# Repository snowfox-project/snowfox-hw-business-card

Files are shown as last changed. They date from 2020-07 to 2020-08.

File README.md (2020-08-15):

# Snowfox HW Business Card

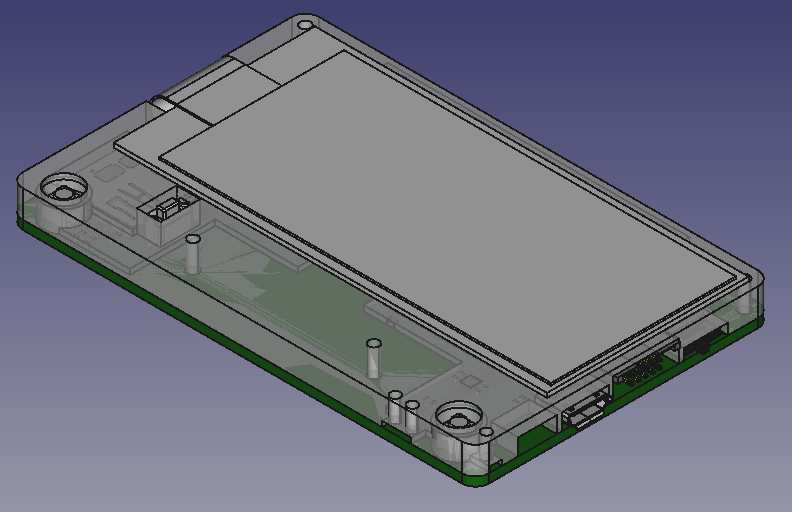
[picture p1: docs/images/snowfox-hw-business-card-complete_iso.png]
snowfox-hw-business-card-complete iso rendering


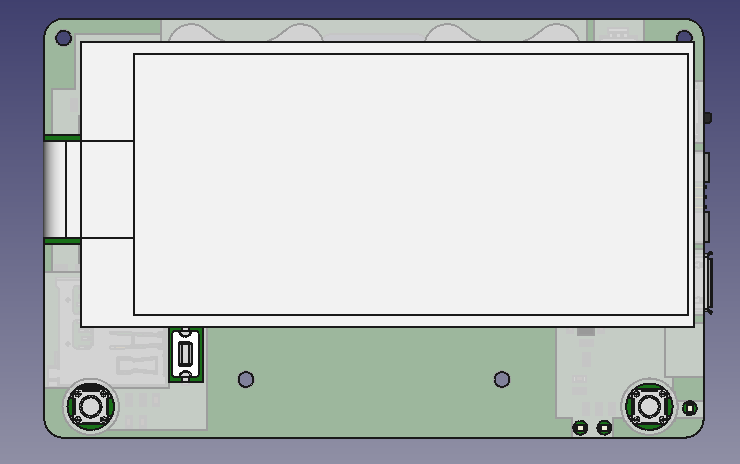
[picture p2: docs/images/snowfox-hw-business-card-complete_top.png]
snowfox-hw-business-card-complete top rendering


## PCB

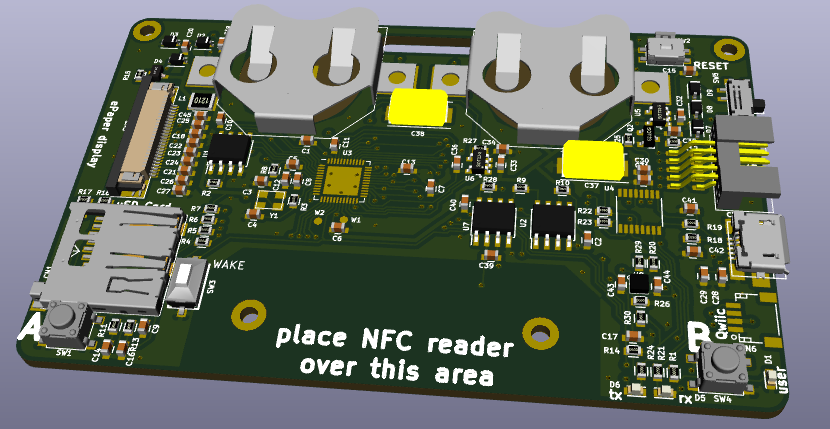
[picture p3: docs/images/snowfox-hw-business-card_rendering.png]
snowfox-hw-business-card rendering


### Top

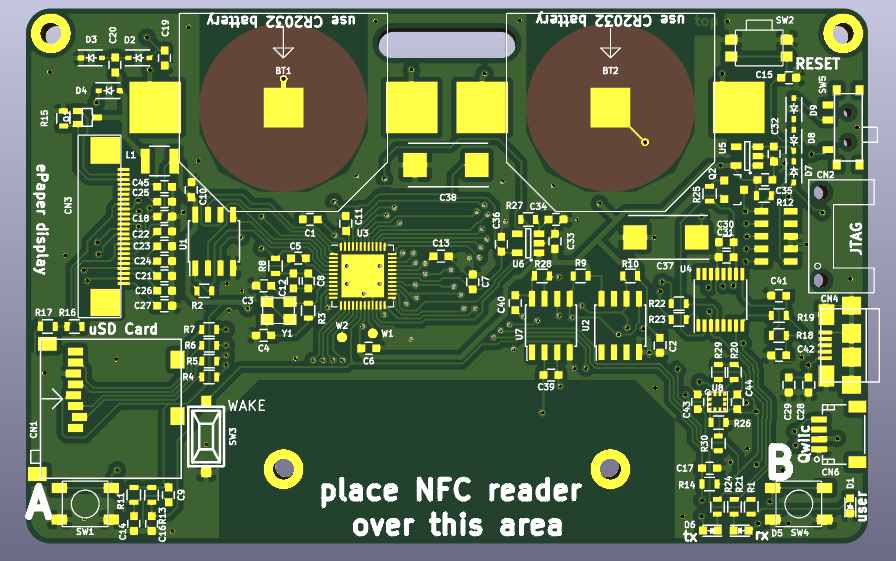
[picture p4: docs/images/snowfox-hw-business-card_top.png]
snowfox-hw-business-card PCB top


### Bottom

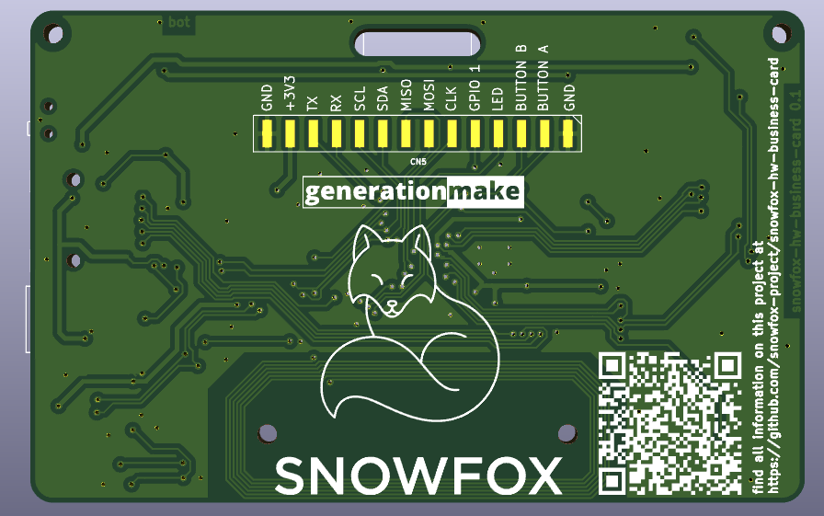
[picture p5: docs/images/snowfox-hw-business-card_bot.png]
snowfox-hw-business-card PCB bot


## Microcontroller

### pin usage

| pin | signal | direction | comment |
|-----|---|---|---|
| gpio_0 | LED | output | user led |
| gpio_1 | GPIO_1 | undefined | |
| gpio_2 | SPI_CS_SD | output | chip select SD card |
| gpio_3 | SPI_MOSI | output | |
| gpio_4 | SPI_MISO | input | |
| gpio_5 | SPI_CLK | output | |
| gpio_9 | SPI_CS_DIS | output | chip selecet display |
| gpio_10 | DIS_RESET# | output | display reset |
| gpio_11 | DIS_D_C# | output | display data/command |
| gpio_12 | I2C_SDA | bidir | I2C data |
| gpio_13 | I2C_SCL | output | I2C clock |
| gpio_16 | RX | input | serial rx to USB |
| gpio_17 | TX | output | serial tx to USB |
| gpio_18 | EXT_TX | output | serial tx to expansion connector |
| gpio_19 | DIS_BUSY | input | display busy |
| gpio_20 | NFC_BUSY | input | nfc busy |
| gpio_21 | BUTTON_A | input | button left |
| gpio_22 | BUTTON_B | input | button right |
| gpio_23 | EXT_RX | input | serial rx to expansion connector |

### i2c addresses

| address | device | comment |
|-----|---|---|
| 0x18 | BMA253 | accelerometer |
| 0x53 | M24LR | NFC eeprom - memory area |
| 0x57 | M24LR | NFC eeprom - security and data area |
| 0x60 | ATECC608A | crypto device |

The M24LR blocks two I2C adresses.

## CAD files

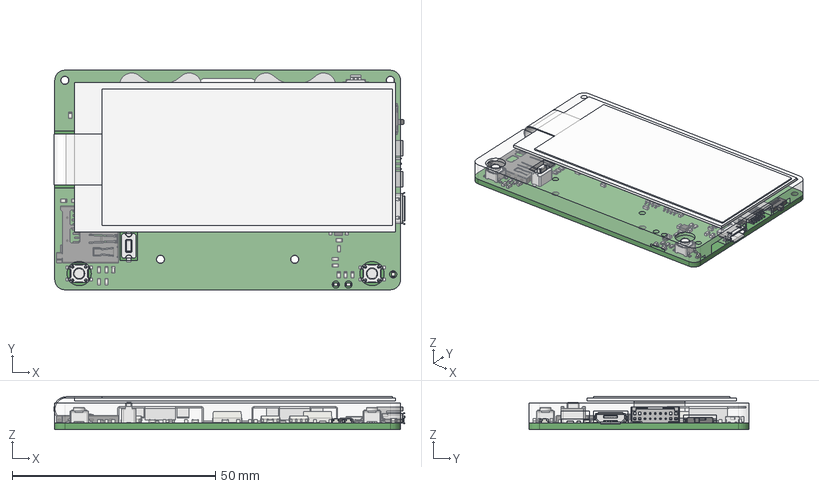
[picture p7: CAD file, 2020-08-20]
freecad_source/snowfox-hw-business-card-complete.FCStd
86.3 x 54.0 x 8.20 mm
display_frame

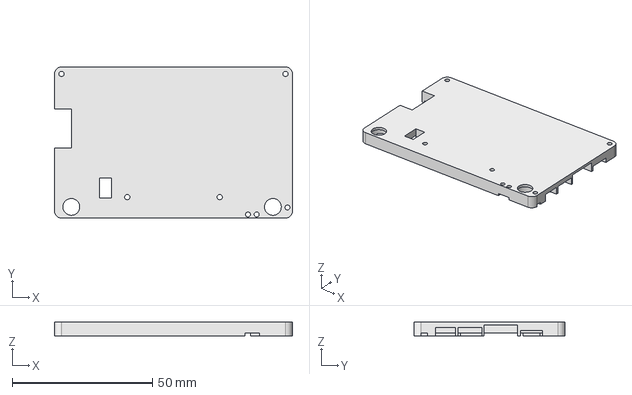
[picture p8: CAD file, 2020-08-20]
production_data/display_frame.step
85.0 x 54.0 x 5.00 mm

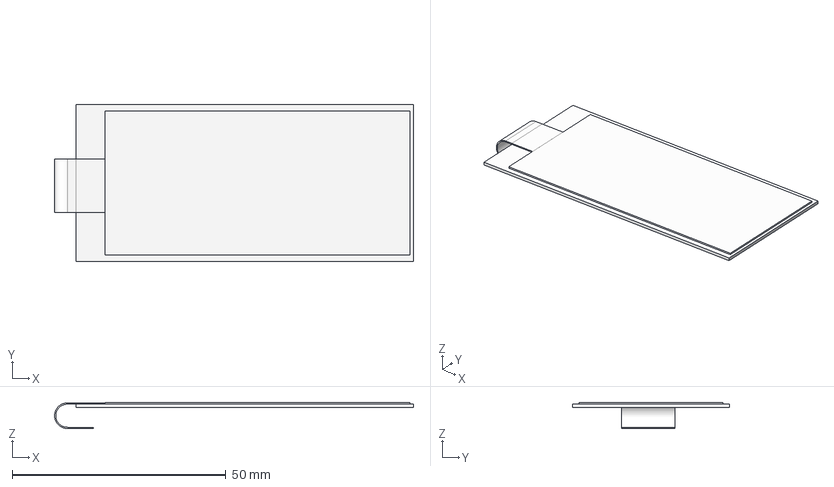
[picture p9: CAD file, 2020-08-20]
freecad_source/e-paper.step
84.0 x 36.7 x 6.10 mm

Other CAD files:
production_data/display_frame.stl

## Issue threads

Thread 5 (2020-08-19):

QR code on pcb silk screen not working

generationmake, 2020-08-19:
fix or remove.

aentinger, 2020-08-31:
I can confirm this. Would it be possible to make a less convoluted QR code? I believe we can't make it much bigger without occupying too much space on the PCB so if it can't be made simpler so that the PCB silkscreen printer can handle it I'd be leaning towards removing it.

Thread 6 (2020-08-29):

add vias in mechanical pads of USB connector

generationmake, 2020-08-29:
add vias to GND on bottom side in mechanical pads of the USB connector to give more mechanical stability and avoid loosening of USB connector (CN4).

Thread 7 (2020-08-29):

mark position of on/off switch in silk screen or similar

generationmake, 2020-08-29:
It is not clear in which position of the on/off switch the board is powered. We should mark the position in the silk screen.

aentinger, 2020-08-31:
I can confirm, it would definitely be helpful to mark both ON/OFF position on the bottom layer silk screen. Furthermore I suggest to also mark QWIIC, USB, JTAG as well as SD card (it doesn't cost any extra as we already print the silk screen at the bottom).

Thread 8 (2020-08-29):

JTAG connector seems to be twisted

generationmake, 2020-08-29:
The JTAG connector CN2 seems to be twisted.

Pin 1 is pin 10 and vice versa and so on.

aentinger, 2020-09-01:
I can confirm this observation. Fortunately this can be solved handily (for me right now) by turning around the plug on the Segger JLink CortexM Adapter.

When connecting with JLinkExe V6.82f I get the following output:
```bash
$ JLinkExe -device FE310 -if JTAG -speed 4000 -jtagconf -1,-1 -autoconnect 1
SEGGER J-Link Commander V6.82f (Compiled Aug 24 2020 12:19:09)
DLL version V6.82f, compiled Aug 24 2020 12:18:57

Connecting to J-Link via USB...O.K.
Firmware: J-Link V10 compiled Jul 17 2020 16:23:38
Hardware version: V10.10
S/N: 50116637
License(s): GDB
VTref=3.335V
Device "FE310" selected.

Connecting to target via JTAG
ConfigTargetSettings() start
ConfigTargetSettings() end
TotalIRLen = 5, IRPrint = 0x01
JTAG chain detection found 1 devices:
 #0 Id: 0x20000913, IRLen: 05, Unknown device
Debug architecture:
  RISC-V debug: 0.13
  AddrBits: 7
  DataBits: 32
  IdleClks: 5
Memory access:
  Via system bus: No
  Via ProgBuf: No (0 ProgBuf entries)
DataBuf: 0 entries
  autoexec[0] implemented: No
Failed to temporarily halt core during identification
Attaching to core failed. Trying again with connect under reset (ndmreset-bit)
Memory access:
Detected: RV32 core
CSR access via abs. commands: Yes
CPU could not be halted
ConfigTargetSettings() start
ConfigTargetSettings() end
ConfigTargetSettings() start
ConfigTargetSettings() end

****** Error: Timeout while waiting for core to halt after reset and halt request
Communication timed out: Requested 4 bytes, received 0 bytes !
Specific core setup failed.
Could not read hardware status!
Cannot connect to target.
J-Link>
```
When connecting to SiFive HiFive 1 Rev. B board I get:
```bash
alex@dragon:~$ JLinkExe -device FE310 -if JTAG -speed 4000 -jtagconf -1,-1 -autoconnect 1
SEGGER J-Link Commander V6.82f (Compiled Aug 24 2020 12:19:09)
DLL version V6.82f, compiled Aug 24 2020 12:18:57

Connecting to J-Link via USB...O.K.
Firmware: J-Link V10 compiled Jul 17 2020 16:23:38
Hardware version: V10.10
S/N: 50116637
License(s): GDB
VTref=3.322V
Device "FE310" selected.

Connecting to target via JTAG
ConfigTargetSettings() start
ConfigTargetSettings() end
TotalIRLen = 5, IRPrint = 0x01
JTAG chain detection found 1 devices:
 #0 Id: 0x20000913, IRLen: 05, Unknown device
Debug architecture:
  RISC-V debug: 0.13
  AddrBits: 7
  DataBits: 32
  IdleClks: 5
Memory access:
  Via system bus: No
  Via ProgBuf: Yes (16 ProgBuf entries)
DataBuf: 1 entries
  autoexec[0] implemented: Yes
Detected: RV32 core
CSR access via abs. commands: No
Temp. halted CPU for NumHWBP detection
HW instruction/data BPs: 8
Support set/clr BPs while running: No
HW data BPs trigger before execution of inst
RISC-V identified.
J-Link>
```
The source of this difference is currently unkown to me.

generationmake, 2020-09-02:
Hi @aentinger
Do you get the same result every time? Have you tried pushing the reset button in between?

Maybe the JLink adapter cannot handle the reset of the board?

Another difference could be the OTP ROM? Maybe it is programmed different?

generationmake, 2020-09-02:
maybe our pull up resistor on reset ist too strong? we have 10k. Hifive1 Rev B has 100k.

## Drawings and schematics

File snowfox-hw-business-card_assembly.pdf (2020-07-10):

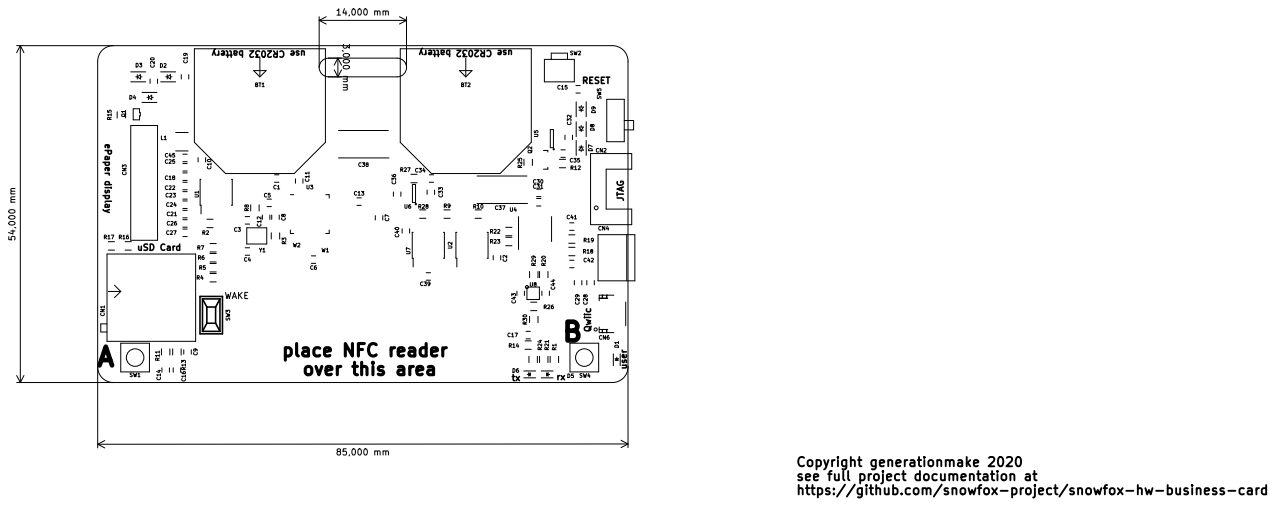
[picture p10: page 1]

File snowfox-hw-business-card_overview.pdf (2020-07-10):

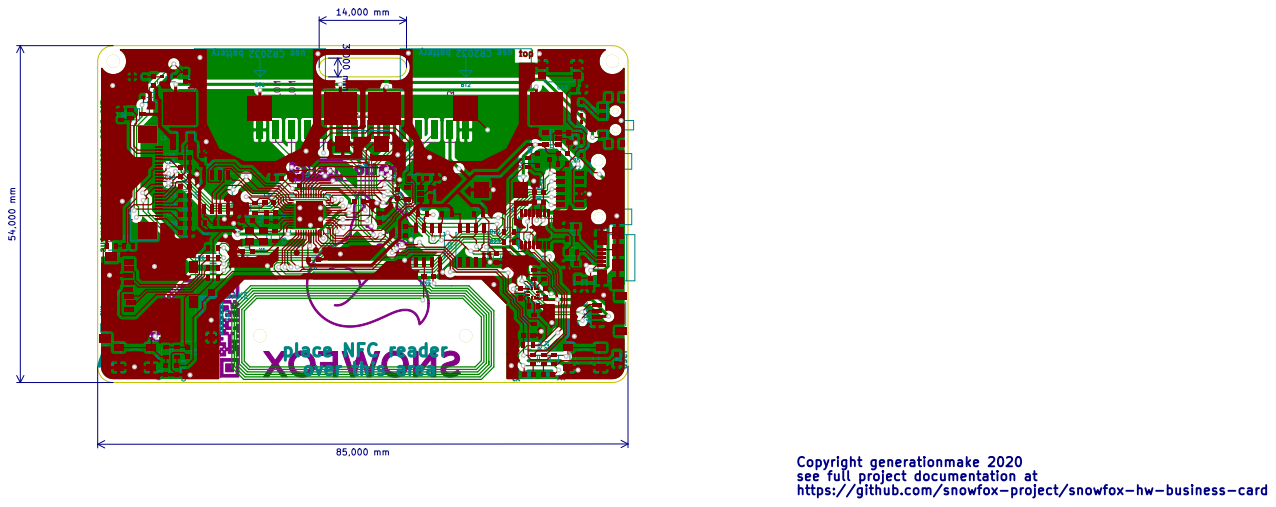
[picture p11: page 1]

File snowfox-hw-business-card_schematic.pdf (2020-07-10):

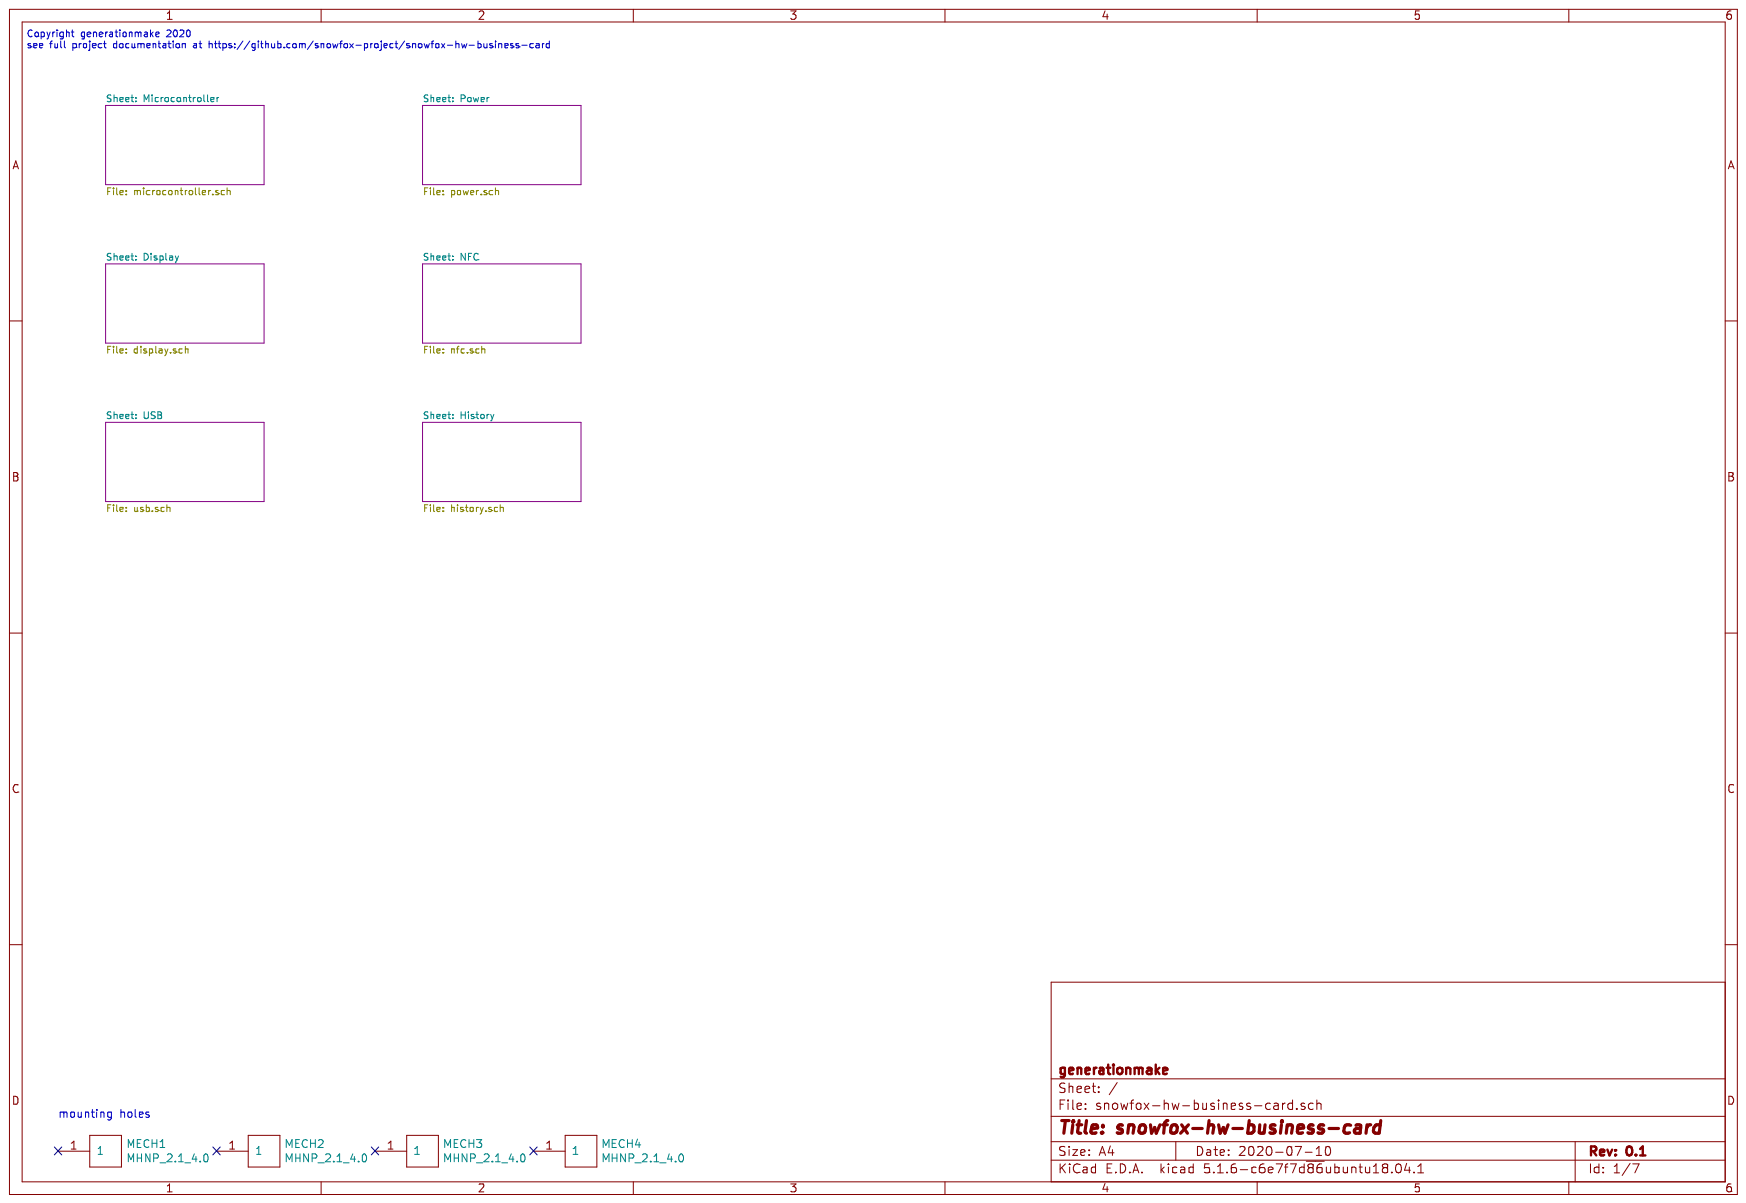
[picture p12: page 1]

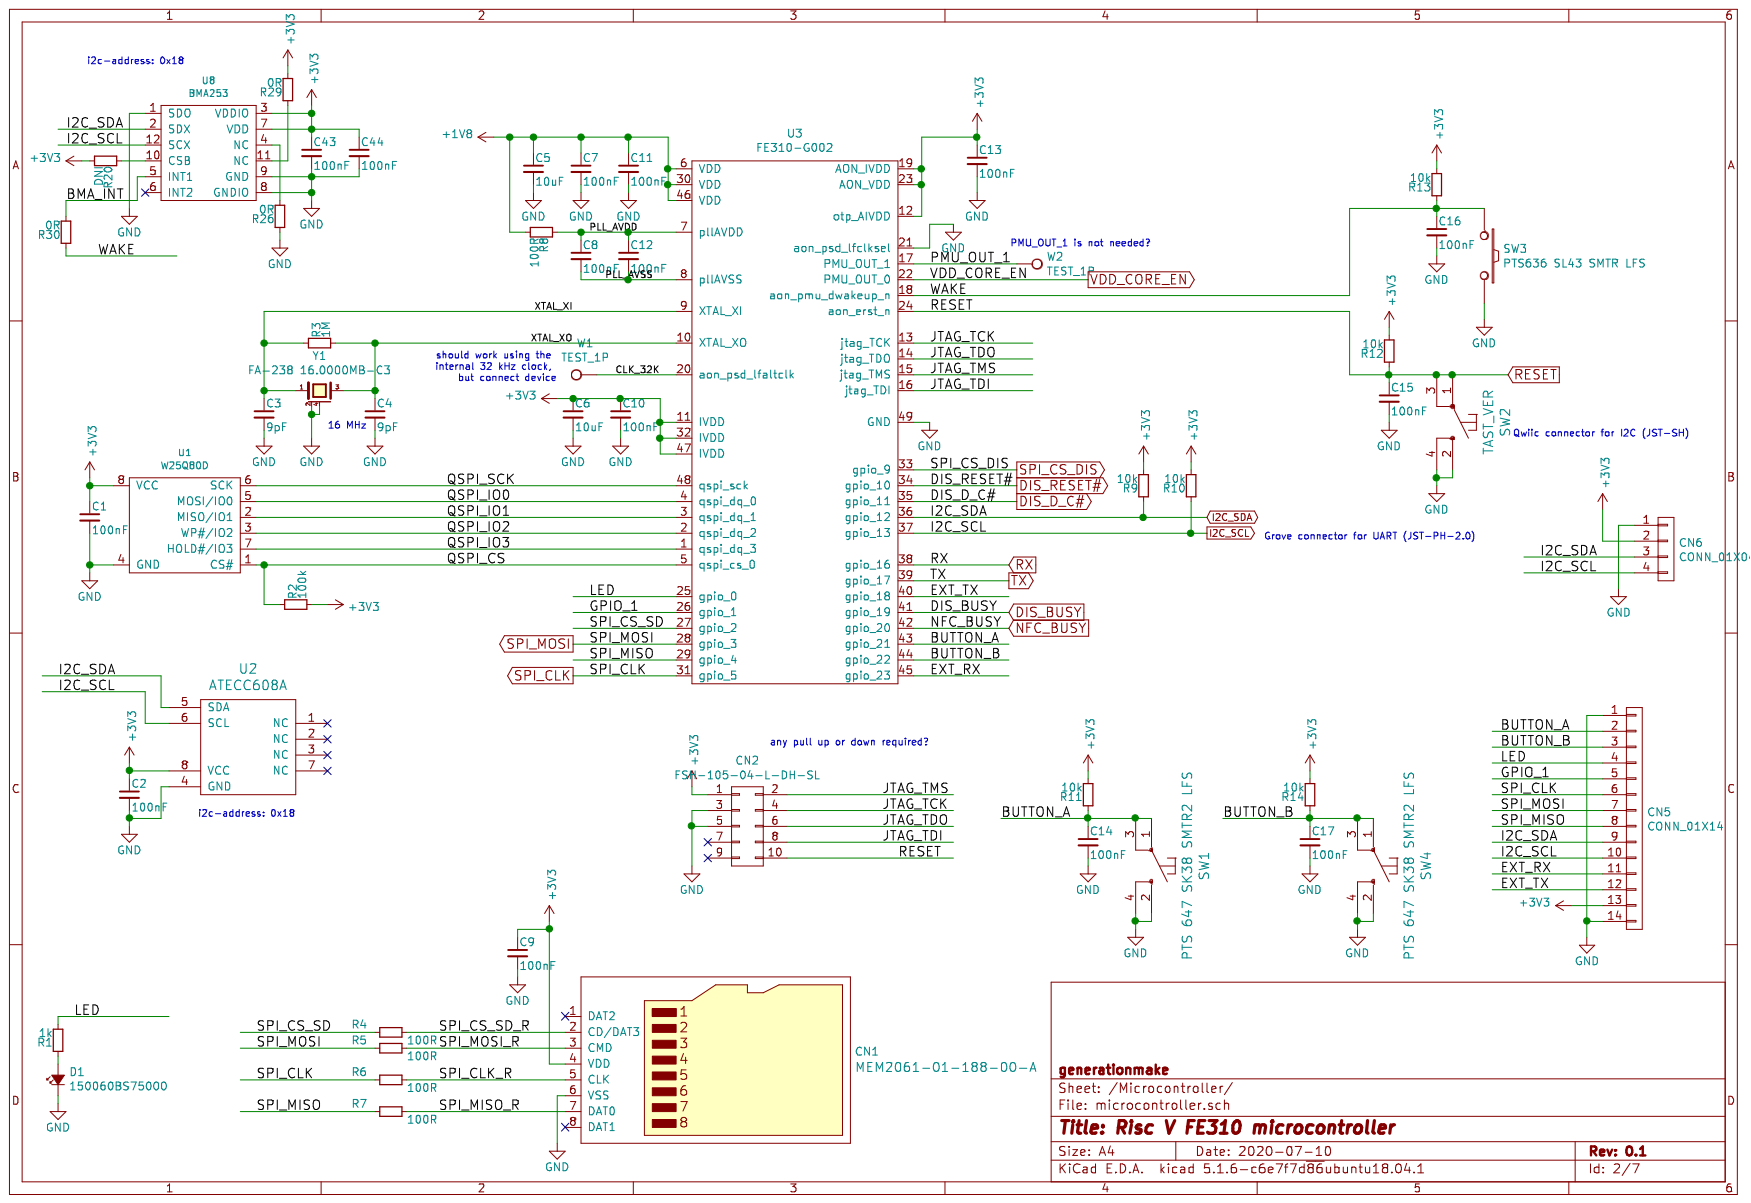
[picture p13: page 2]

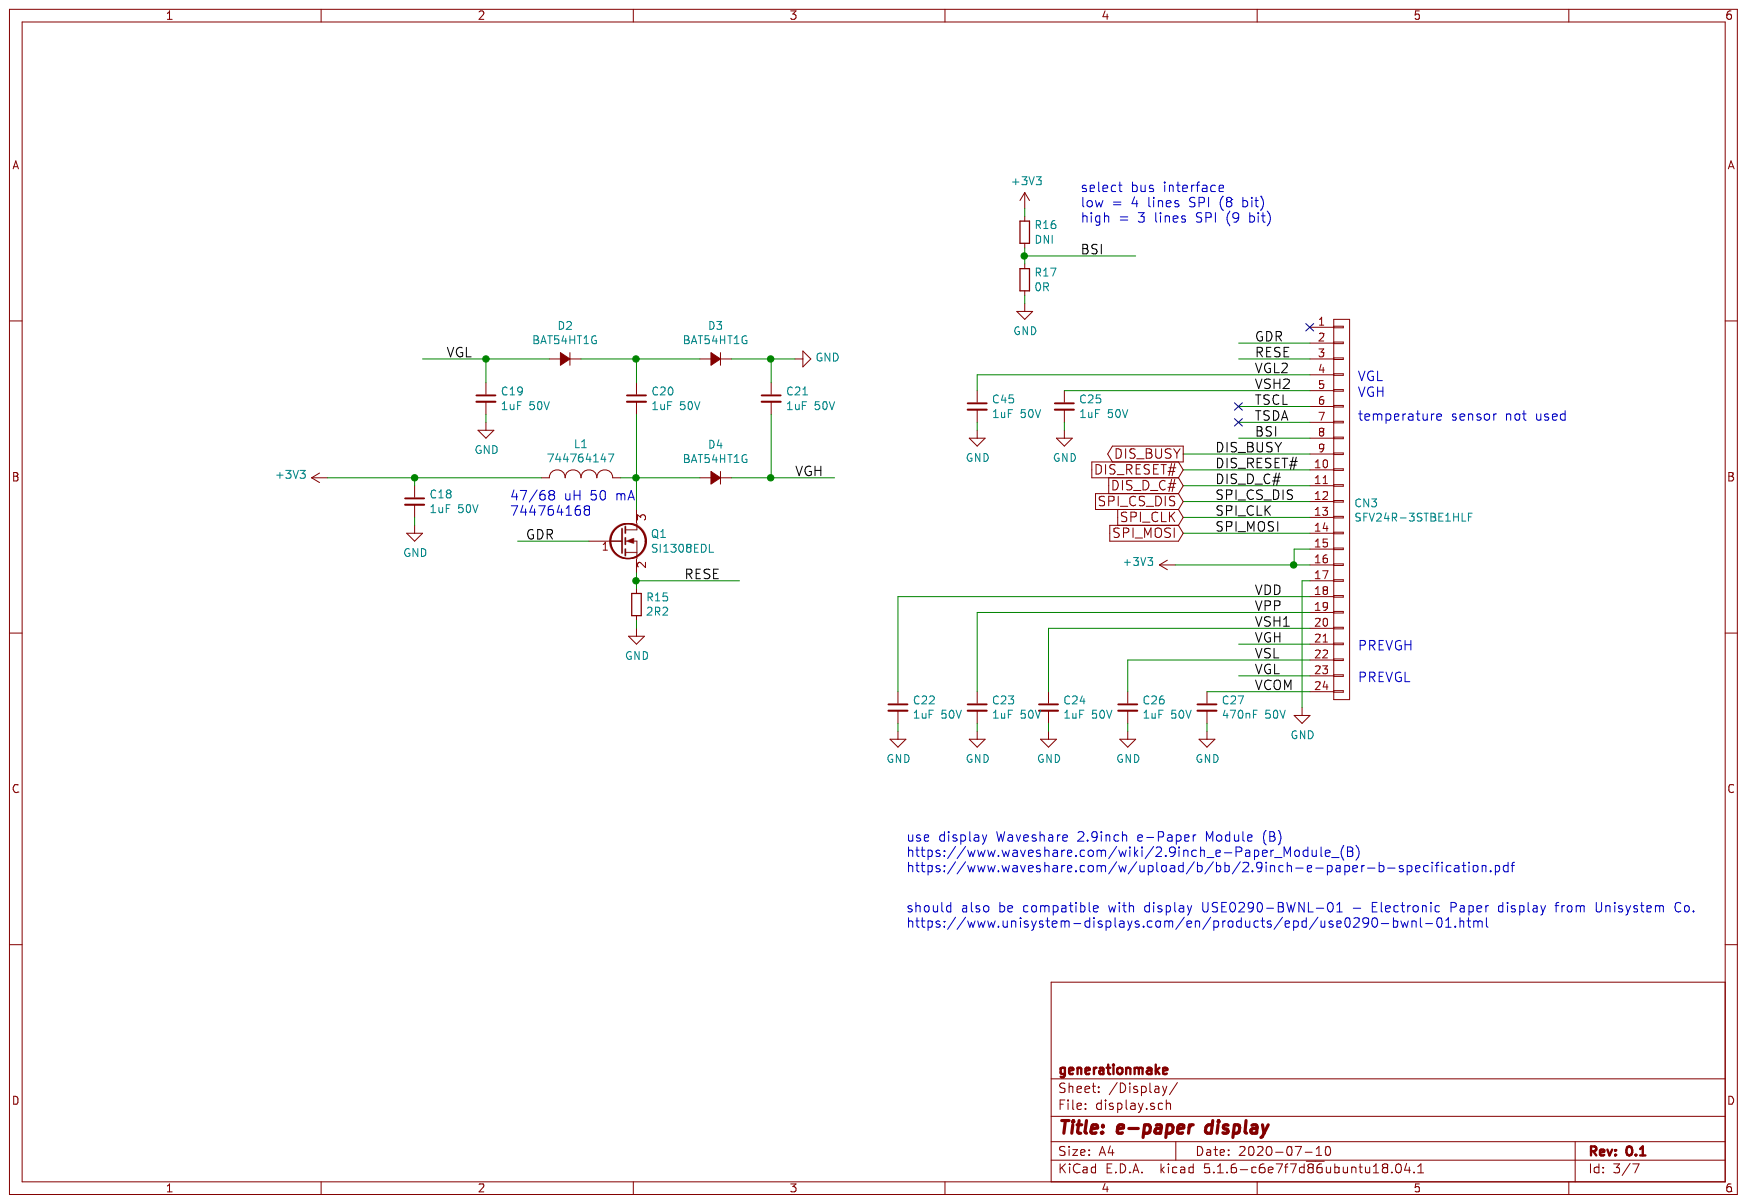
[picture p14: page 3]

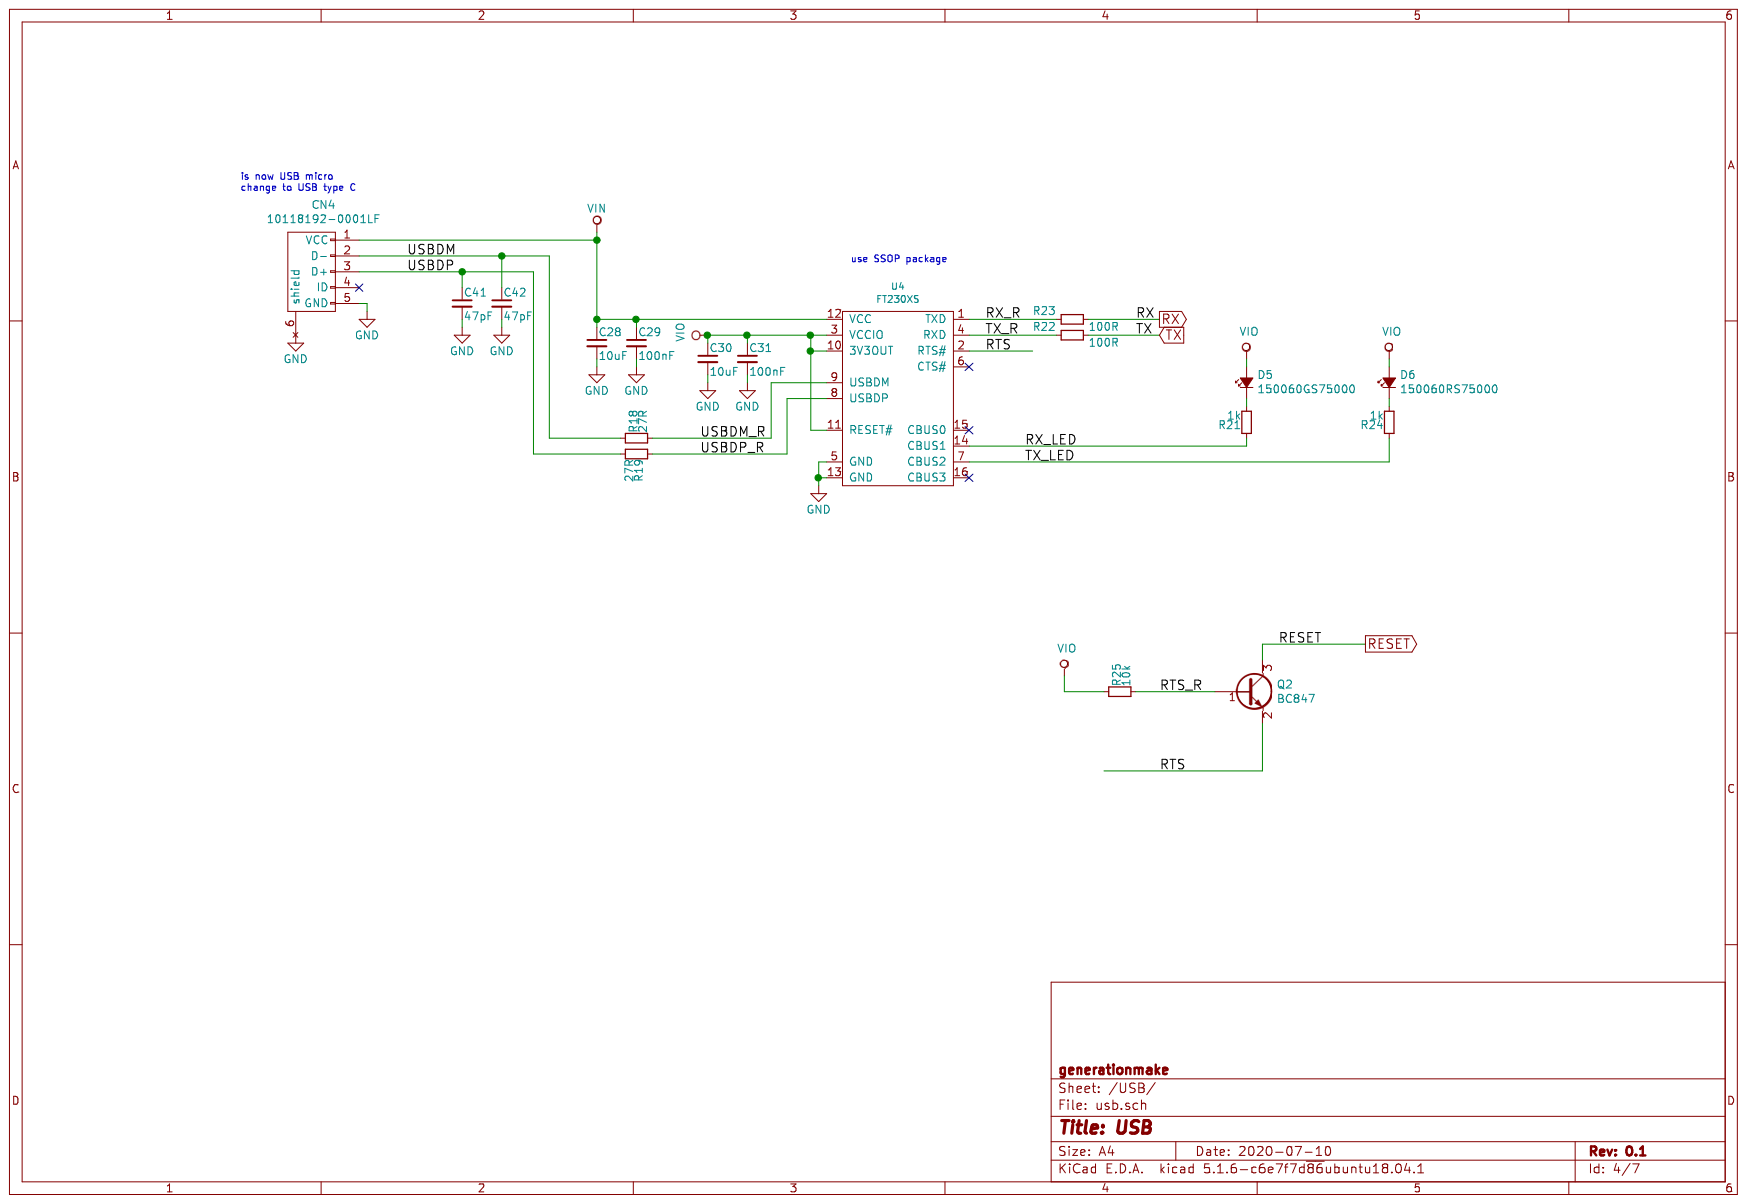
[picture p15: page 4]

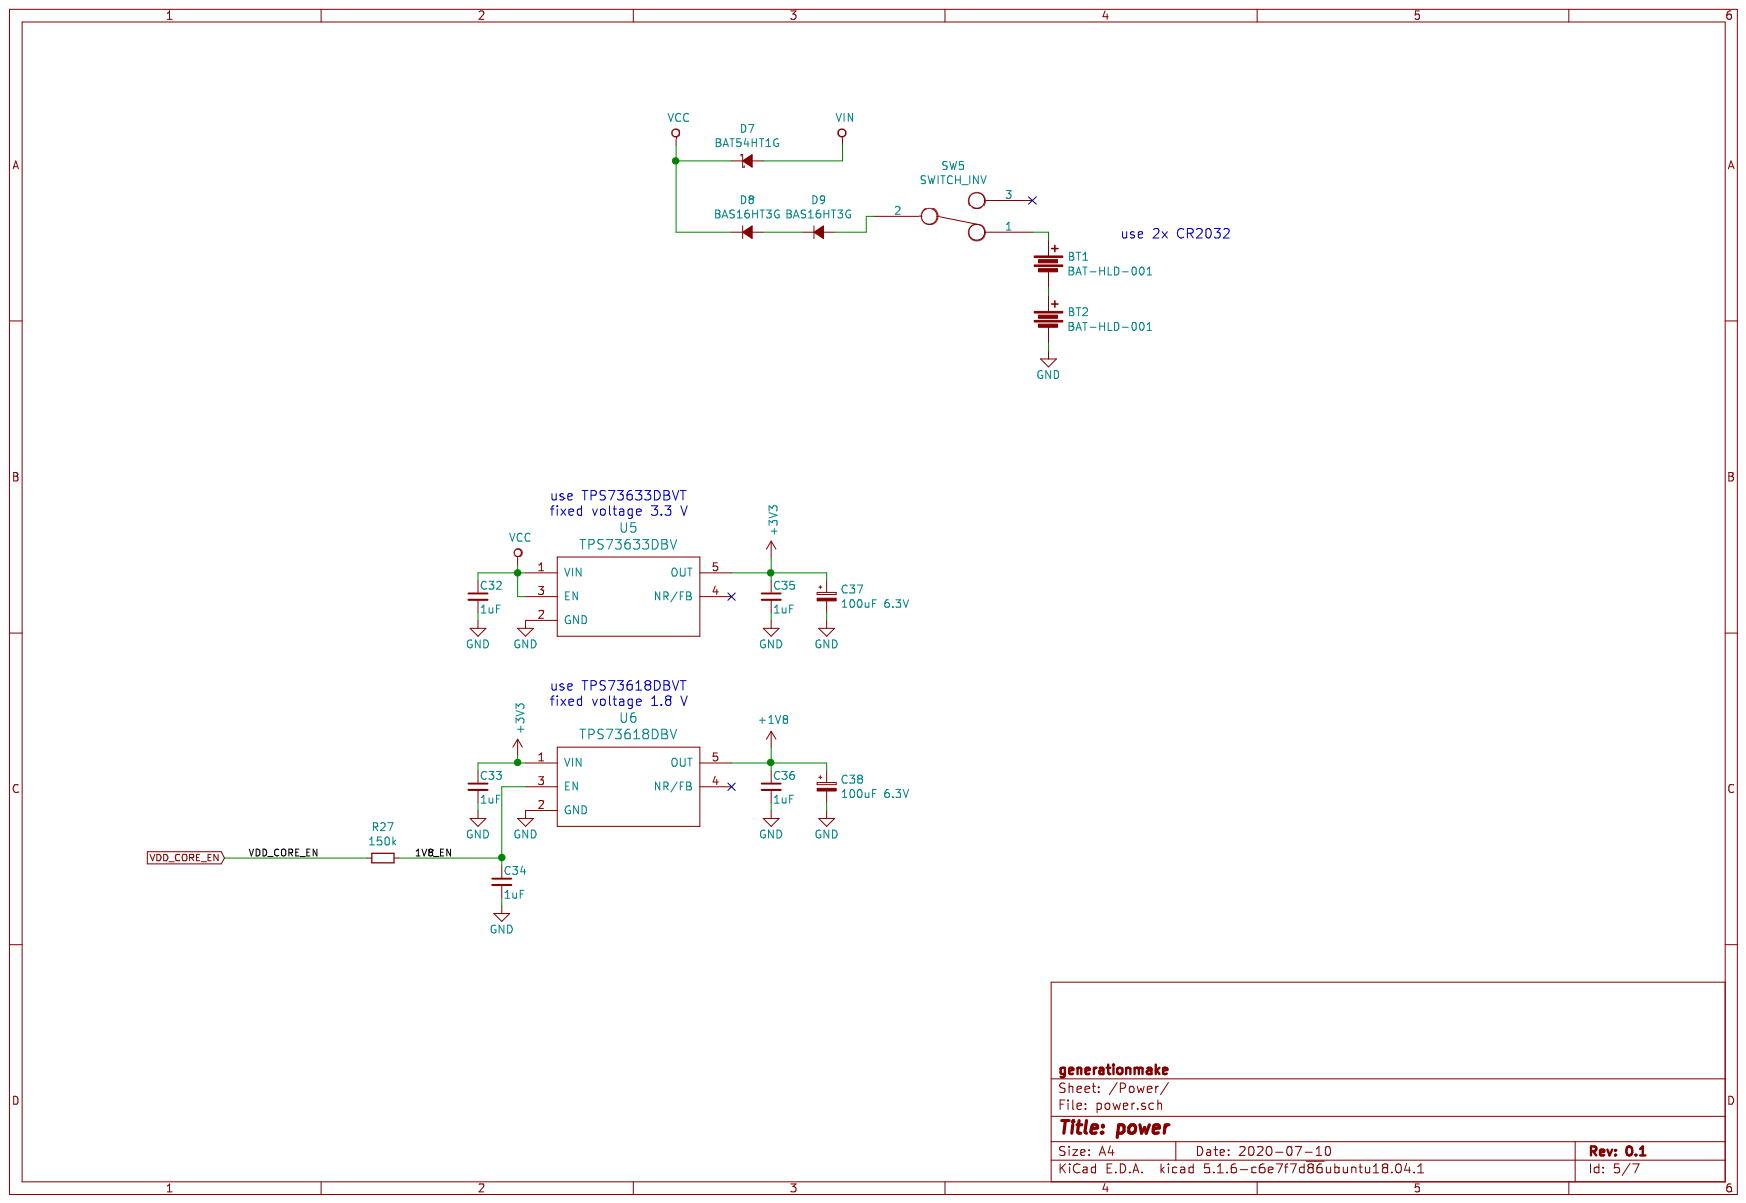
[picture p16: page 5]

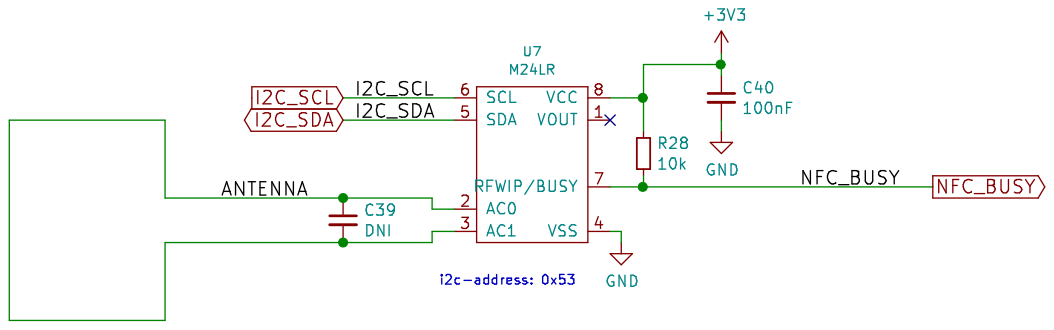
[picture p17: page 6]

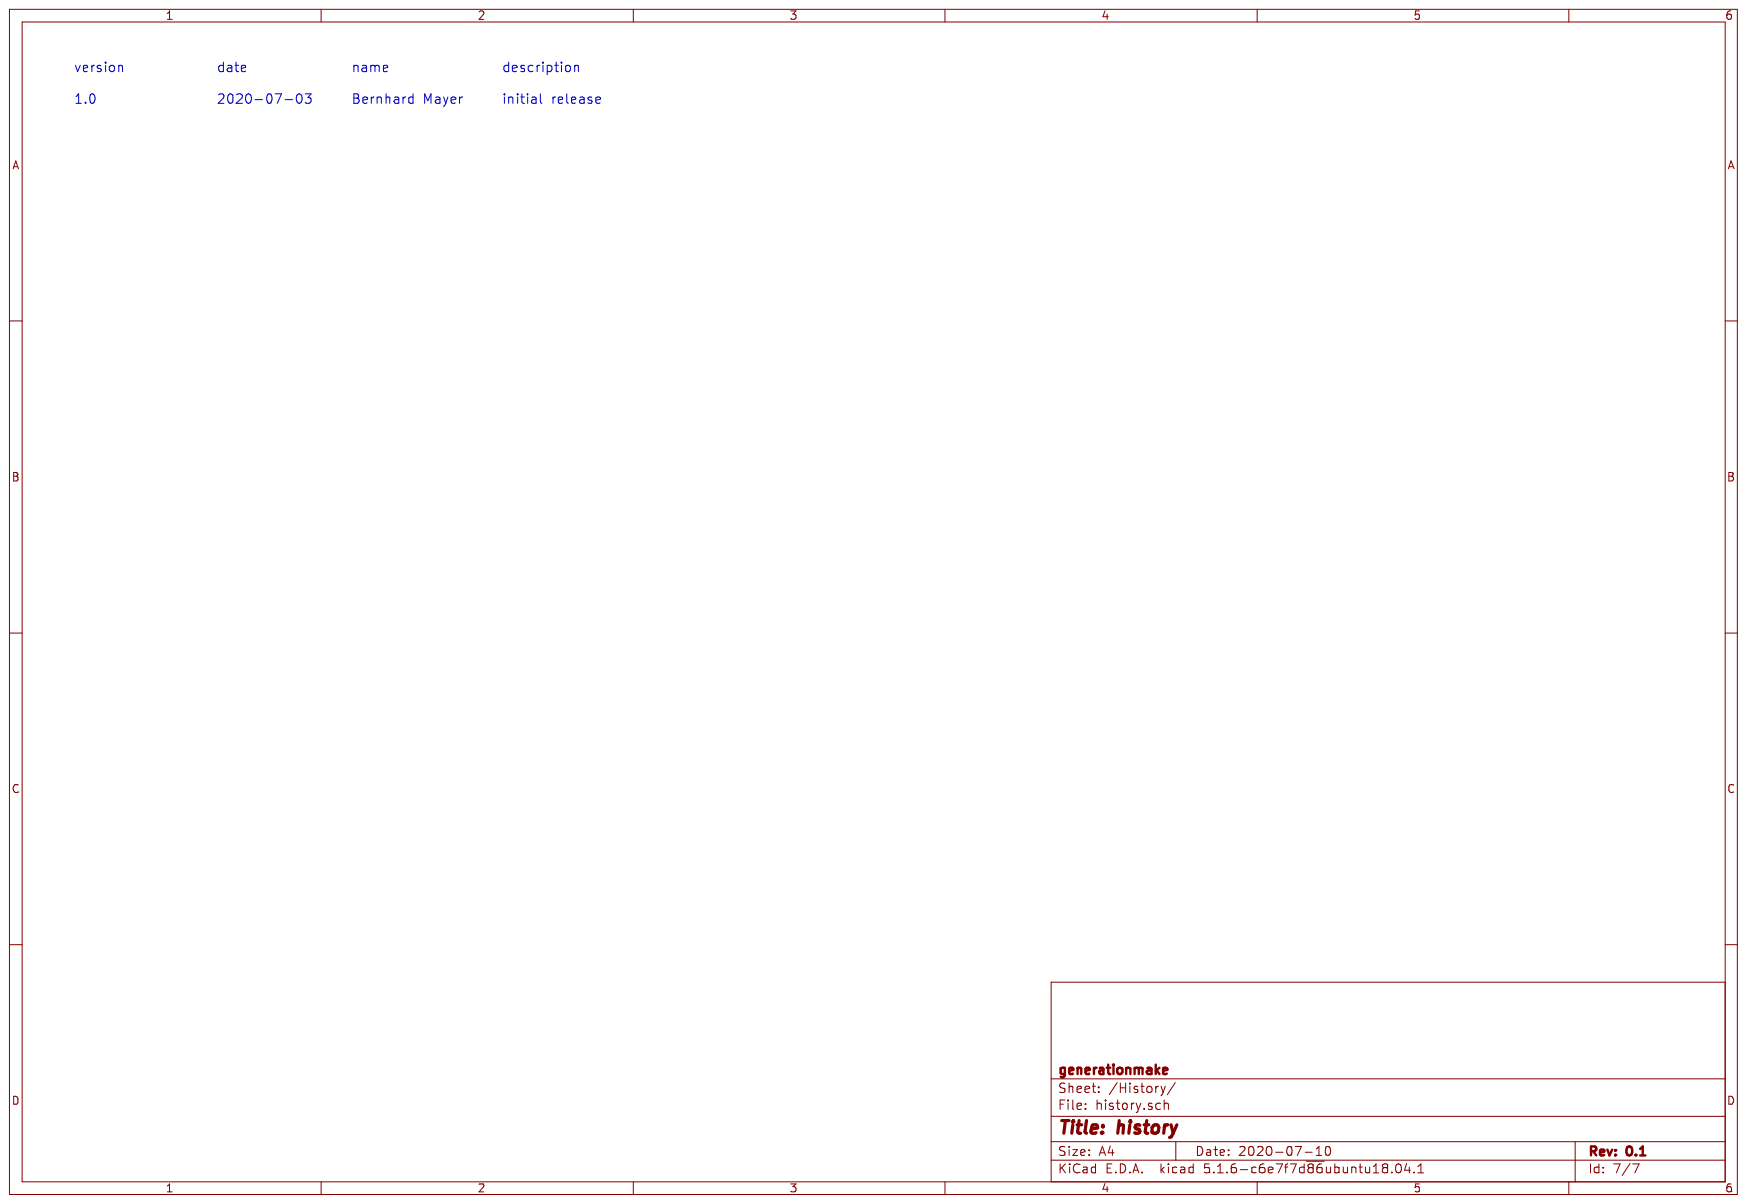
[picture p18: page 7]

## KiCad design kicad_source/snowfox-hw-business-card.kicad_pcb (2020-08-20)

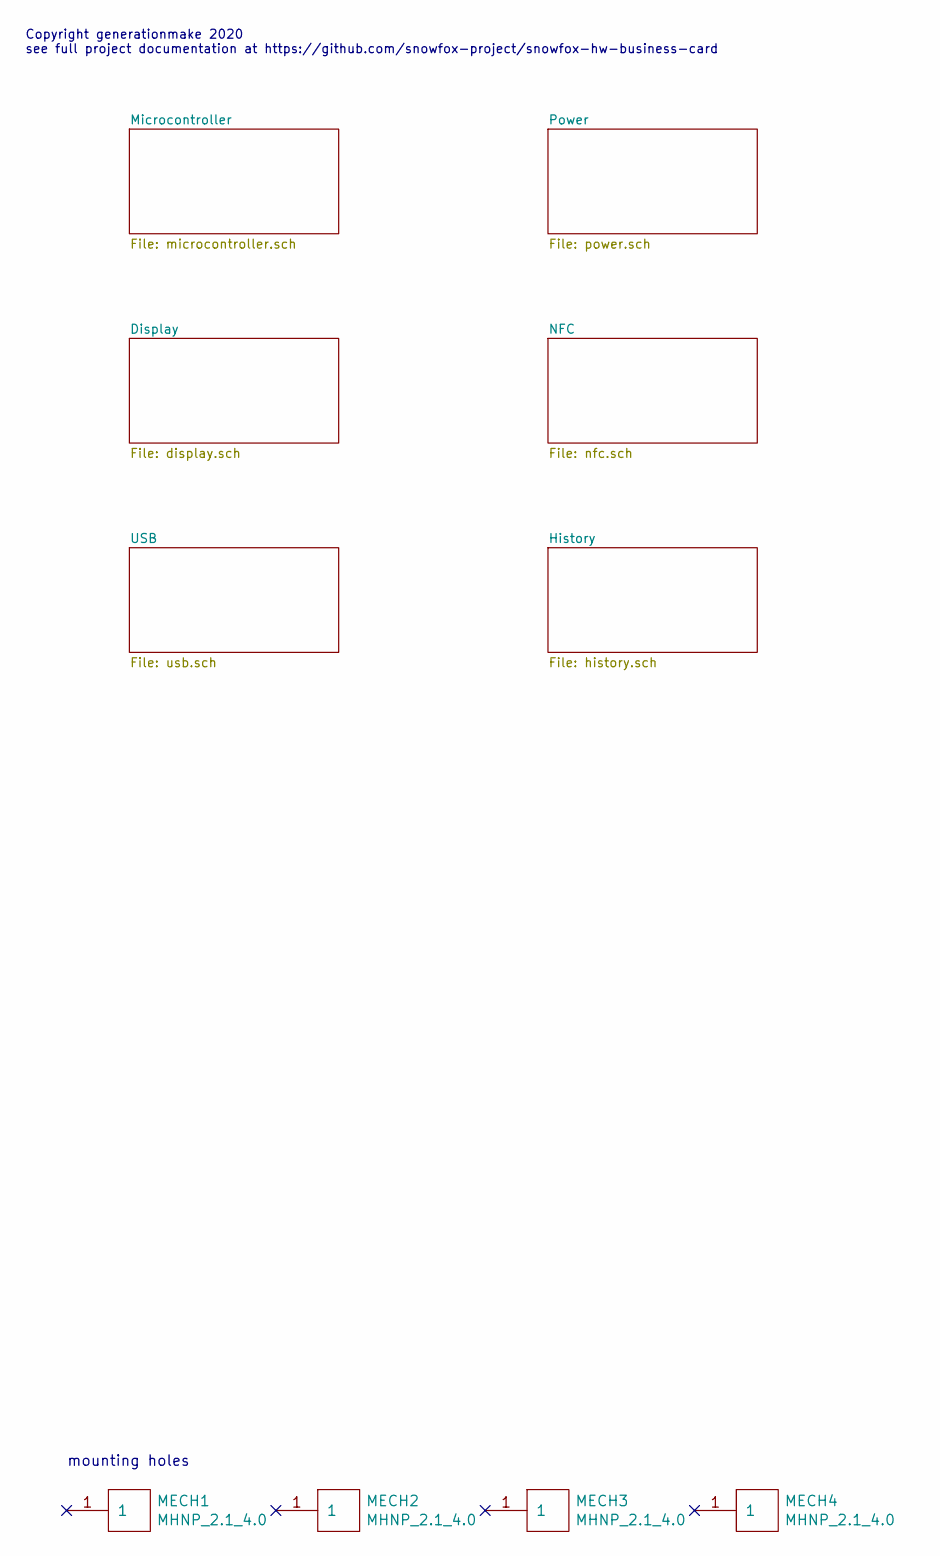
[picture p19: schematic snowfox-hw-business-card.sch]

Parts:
MECH1, MECH2, MECH3, MECH4: MHNP_2.1_4.0; MH_210_400_NP

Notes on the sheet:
mounting holes
Copyright generationmake 2020 see full project documentation at https://github.com/snowfox-project/snowfox-hw-business-card

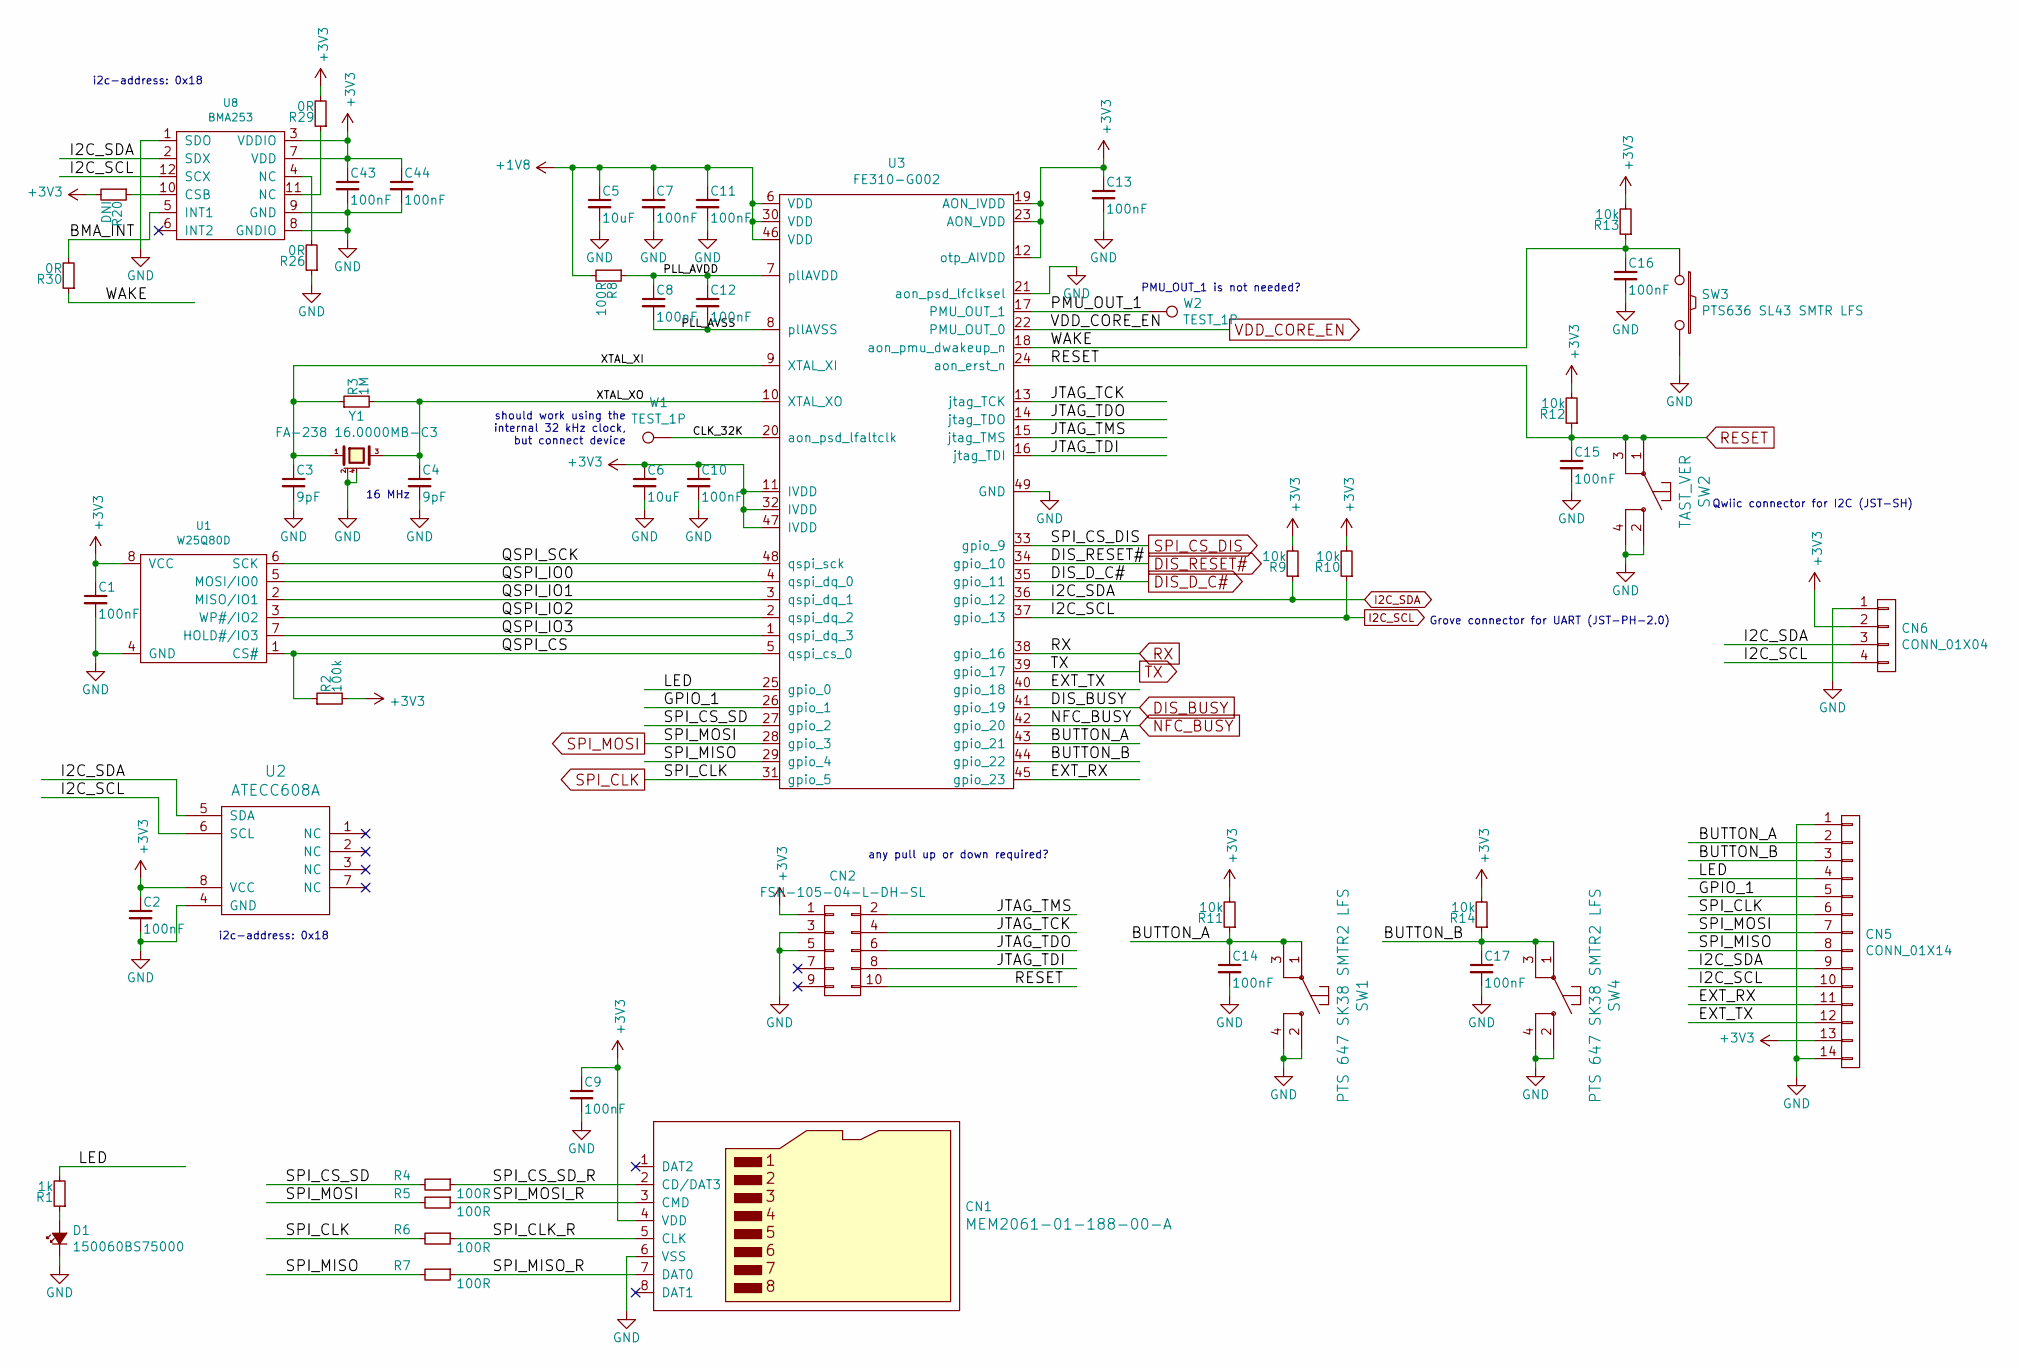
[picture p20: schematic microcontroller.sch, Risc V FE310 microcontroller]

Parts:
C1, C2, C7, C8, C9, C10, C11, C12, C13, C14, C15, C16, C17, C43, C44: 100nF; C_0603
C3, C4: 9pF; C_0603
C5, C6: 10uF; C_0603
CN1: MEM2061-01-188-00-A; WE_693071010811
CN2: FSH-105-04-L-DH-SL
CN5: CONN_01X14; SIB-114-02-F-S_MATING
CN6: CONN_01X04; Connectors_JST_SM04B-SRSS-TB
D1: 150060BS75000; LED_0603
R1: 1k; R_0603
R2: 100k; R_0603
R3: 1M; R_0603
R4, R5, R6, R7, R8: 100R; R_0603
R9, R10, R11, R12, R13, R14: 10k; R_0603
R20: DNI; R_0603
R26, R29, R30: 0R; R_0603
SW1, SW4: PTS 647 SK38 SMTR2 LFS; CK_PTS647
SW2: TAST_VER; WE_434351045816
SW3: PTS636 SL43 SMTR LFS; WE_434121050816
U1: W25Q80D; SOIC-8_3.9x4.9mm_Pitch1.27mm
U2: ATECC608A; SOIC-8_3.9x4.9mm_Pitch1.27mm
U3: FE310-G002; QFN-48-1EP_6x6mm_P0.4mm_EP4.3x4.3mm
U8: BMA253; BMA400
W1, W2: TEST_1P; SolderWirePad_single_1mmSMD
Y1: FA-238 16.0000MB-C3; Crystal_SMD_3.2x2.5mm_4Pad

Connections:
+1V8: C5.1, C7.1, C11.1, R8.2, U3.6 (VDD), U3.30 (VDD), U3.46 (VDD); also elsewhere on the board
+3V3: C1.1, C2.1, C6.1, C9.1, C10.1, C13.1, C43.1, C44.1, CN1.4 (VDD), CN2.1, CN5.13, CN6.2, R2.2, R9.2, R10.2, R11.2, R12.2, R13.2, R14.2, R20.2, R29.2, U1.8 (VCC), U2.8 (VCC), U3.11 (IVDD), U3.12 (otp_AIVDD), U3.19 (AON_IVDD), U3.23 (AON_VDD), U3.32 (IVDD), U3.47 (IVDD), U8.3 (VDDIO), U8.7 (VDD); also elsewhere on the board
/Microcontroller/BMA_INT: R30.2, U8.5 (INT1)
/Microcontroller/BUTTON_A: C14.1, CN5.2, R11.1, SW1.1, SW1.3, U3.43 (gpio_21)
/Microcontroller/BUTTON_B: C17.1, CN5.3, R14.1, SW4.1, SW4.3, U3.44 (gpio_22)
/Microcontroller/CLK_32K: U3.20 (aon_psd_lfaltclk), W1.1
/Microcontroller/EXT_RX: CN5.11, U3.45 (gpio_23)
/Microcontroller/EXT_TX: CN5.12, U3.40 (gpio_18)
/Microcontroller/GPIO_1: CN5.5, U3.26 (gpio_1)
/Microcontroller/JTAG_TCK: CN2.4, U3.13 (jtag_TCK)
/Microcontroller/JTAG_TDI: CN2.8, U3.16 (jtag_TDI)
/Microcontroller/JTAG_TDO: CN2.6, U3.14 (jtag_TDO)
/Microcontroller/JTAG_TMS: CN2.2, U3.15 (jtag_TMS)
/Microcontroller/LED: CN5.4, R1.2, U3.25 (gpio_0)
/Microcontroller/PLL_AVDD: C8.1, C12.1, R8.1, U3.7 (pllAVDD)
/Microcontroller/PLL_AVSS: C8.2, C12.2, U3.8 (pllAVSS)
/Microcontroller/PMU_OUT_1: U3.17 (PMU_OUT_1), W2.1
/Microcontroller/QSPI_CS: R2.1, U1.1 (CS#), U3.5 (qspi_cs_0)
/Microcontroller/QSPI_IO0: U1.5 (MOSI/IO0), U3.4 (qspi_dq_0)
/Microcontroller/QSPI_IO1: U1.2 (MISO/IO1), U3.3 (qspi_dq_1)
/Microcontroller/QSPI_IO2: U1.3 (WP#/IO2), U3.2 (qspi_dq_2)
/Microcontroller/QSPI_IO3: U1.7 (HOLD#/IO3), U3.1 (qspi_dq_3)
/Microcontroller/QSPI_SCK: U1.6 (SCK), U3.48 (qspi_sck)
/Microcontroller/SPI_CLK_R: CN1.5 (CLK), R6.1
/Microcontroller/SPI_CS_SD: R4.2, U3.27 (gpio_2)
/Microcontroller/SPI_CS_SD_R: CN1.2 (CD/DAT3), R4.1
/Microcontroller/SPI_MISO: CN5.8, R7.2, U3.29 (gpio_4)
/Microcontroller/SPI_MISO_R: CN1.7 (DAT0), R7.1
/Microcontroller/SPI_MOSI_R: CN1.3 (CMD), R5.1
/Microcontroller/WAKE: C16.1, R13.1, R30.1, SW3.1, U3.18 (aon_pmu_dwakeup_n)
/Microcontroller/XTAL_XI: C3.1, R3.1, U3.9 (XTAL_XI), Y1.1
/Microcontroller/XTAL_XO: C4.1, R3.2, U3.10 (XTAL_XO), Y1.3
DIS_BUSY: U3.41 (gpio_19); also elsewhere on the board
DIS_D_C#: U3.35 (gpio_11); also elsewhere on the board
DIS_RESET#: U3.34 (gpio_10); also elsewhere on the board
GND: C1.2, C2.2, C3.2, C4.2, C5.2, C6.2, C7.2, C9.2, C10.2, C11.2, C13.2, C14.2, C15.2, C16.2, C17.2, C43.2, C44.2, CN1.6 (VSS), CN2.3, CN2.5, CN5.1, CN5.14, CN6.1, D1.1 (K), R26.1, SW1.2, SW1.4, SW2.2, SW2.4, SW3.2, SW4.2, SW4.4, U1.4 (GND), U2.4 (GND), U3.21 (aon_psd_lfclksel), U3.49 (GND), U8.1 (SDO), U8.8 (GNDIO), U8.9 (GND), Y1.2 (case), Y1.4 (case); also elsewhere on the board
I2C_SCL: CN5.10, CN6.4, R10.1, U2.6 (SCL), U3.37 (gpio_13), U8.12 (SCX); also elsewhere on the board
I2C_SDA: CN5.9, CN6.3, R9.1, U2.5 (SDA), U3.36 (gpio_12), U8.2 (SDX); also elsewhere on the board
NFC_BUSY: U3.42 (gpio_20); also elsewhere on the board
unnamed: D1.2 (A), R1.1
unnamed: R20.1, U8.10 (CSB)
unnamed: R26.2, U8.4 (NC)
unnamed: R29.1, U8.11 (NC)
RESET: C15.1, CN2.10, R12.1, SW2.1, SW2.3, U3.24 (aon_erst_n); also elsewhere on the board
RX: U3.38 (gpio_16); also elsewhere on the board
SPI_CLK: CN5.6, R6.2, U3.31 (gpio_5); also elsewhere on the board
SPI_CS_DIS: U3.33 (gpio_9); also elsewhere on the board
SPI_MOSI: CN5.7, R5.2, U3.28 (gpio_3); also elsewhere on the board
TX: U3.39 (gpio_17); also elsewhere on the board
VDD_CORE_EN: U3.22 (PMU_OUT_0); also elsewhere on the board

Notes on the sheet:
should work using the internal 32 kHz clock, but connect device
PMU_OUT_1 is not needed?
any pull up or down required?
Qwiic connector for I2C (JST-SH)
Grove connector for UART (JST-PH-2.0)
16 MHz
i2c-address: 0x18

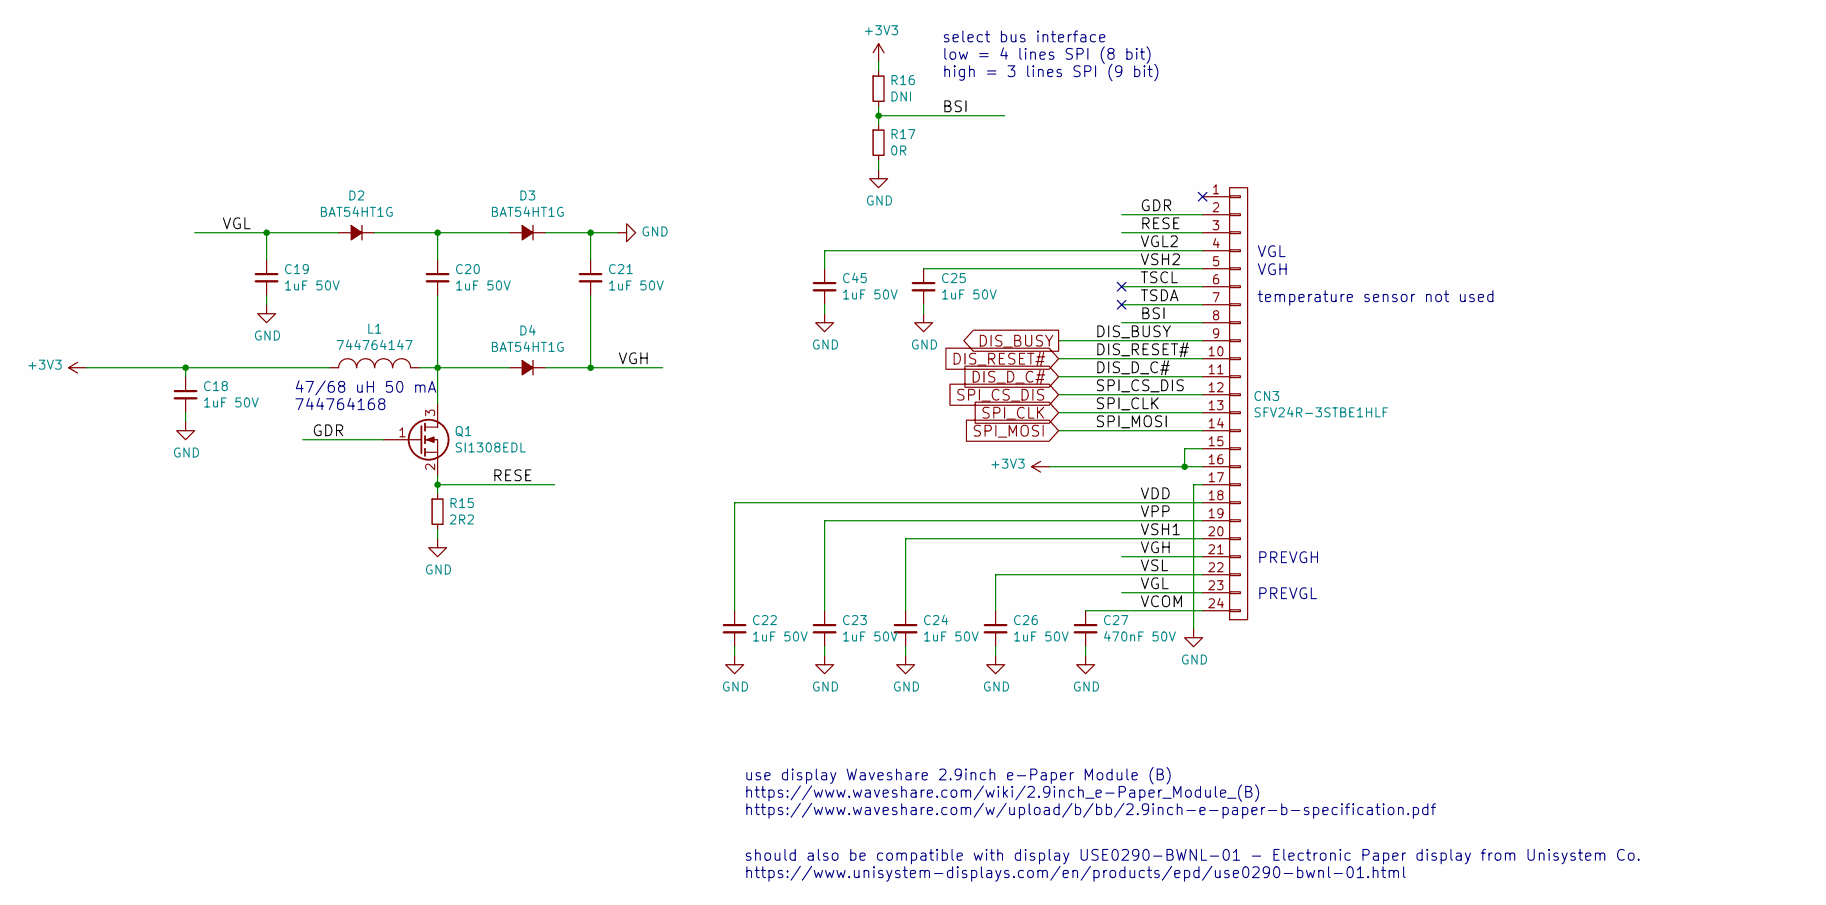
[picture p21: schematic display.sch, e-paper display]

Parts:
C18, C19, C20, C21, C22, C23, C24, C25, C26, C45: 1uF 50V; C_0603
C27: 470nF 50V; C_0603
CN3: SFV24R-3STBE1HLF; WR-FPC_68712414522
D2, D3, D4: BAT54HT1G; SOD-323
L1: 744764147; R_1210
Q1: SI1308EDL; SOT-323
R15: 2R2; R_0603
R16: DNI; R_0603
R17: 0R; R_0603

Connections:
+3V3: C18.1, CN3.15, CN3.16, L1.1, R16.1; also elsewhere on the board
/Display/BSI: CN3.8, R16.2, R17.1
/Display/GDR: CN3.2, Q1.1 (G)
/Display/RESE: CN3.3, Q1.2 (S), R15.1
/Display/VCOM: C27.1, CN3.24
/Display/VDD: C22.1, CN3.18
/Display/VGH: C21.2, CN3.21, D4.1 (K)
/Display/VGL: C19.1, CN3.23, D2.2 (A)
/Display/VGL2: C45.1, CN3.4
/Display/VPP: C23.1, CN3.19
/Display/VSH1: C24.1, CN3.20
/Display/VSH2: C25.1, CN3.5
/Display/VSL: C26.1, CN3.22
DIS_BUSY: CN3.9; also elsewhere on the board
DIS_D_C#: CN3.11; also elsewhere on the board
DIS_RESET#: CN3.10; also elsewhere on the board
GND: C18.2, C19.2, C21.1, C22.2, C23.2, C24.2, C25.2, C26.2, C27.2, C45.2, CN3.17, D3.1 (K), R15.2, R17.2; also elsewhere on the board
unnamed: C20.1, D2.1 (K), D3.2 (A)
unnamed: C20.2, D4.2 (A), L1.2, Q1.3 (D)
SPI_CLK: CN3.13; also elsewhere on the board
SPI_CS_DIS: CN3.12; also elsewhere on the board
SPI_MOSI: CN3.14; also elsewhere on the board

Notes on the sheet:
temperature sensor not used
select bus interface low = 4 lines SPI (8 bit) high = 3 lines SPI (9 bit)
use display Waveshare 2.9inch e-Paper Module (B) https://www.waveshare.com/wiki/2.9inch_e-Paper_Module_(B) https://www.waveshare.com/w/upload/b/bb/2.9inch-e-paper-b-specification.pdf
47/68 uH 50 mA 744764168
should also be compatible with display USE0290-BWNL-01 - Electronic Paper display from Unisystem Co. https://www.unisystem-displays.com/en/products/epd/use0290-bwnl-01.html
VGL
VGH
PREVGH
PREVGL

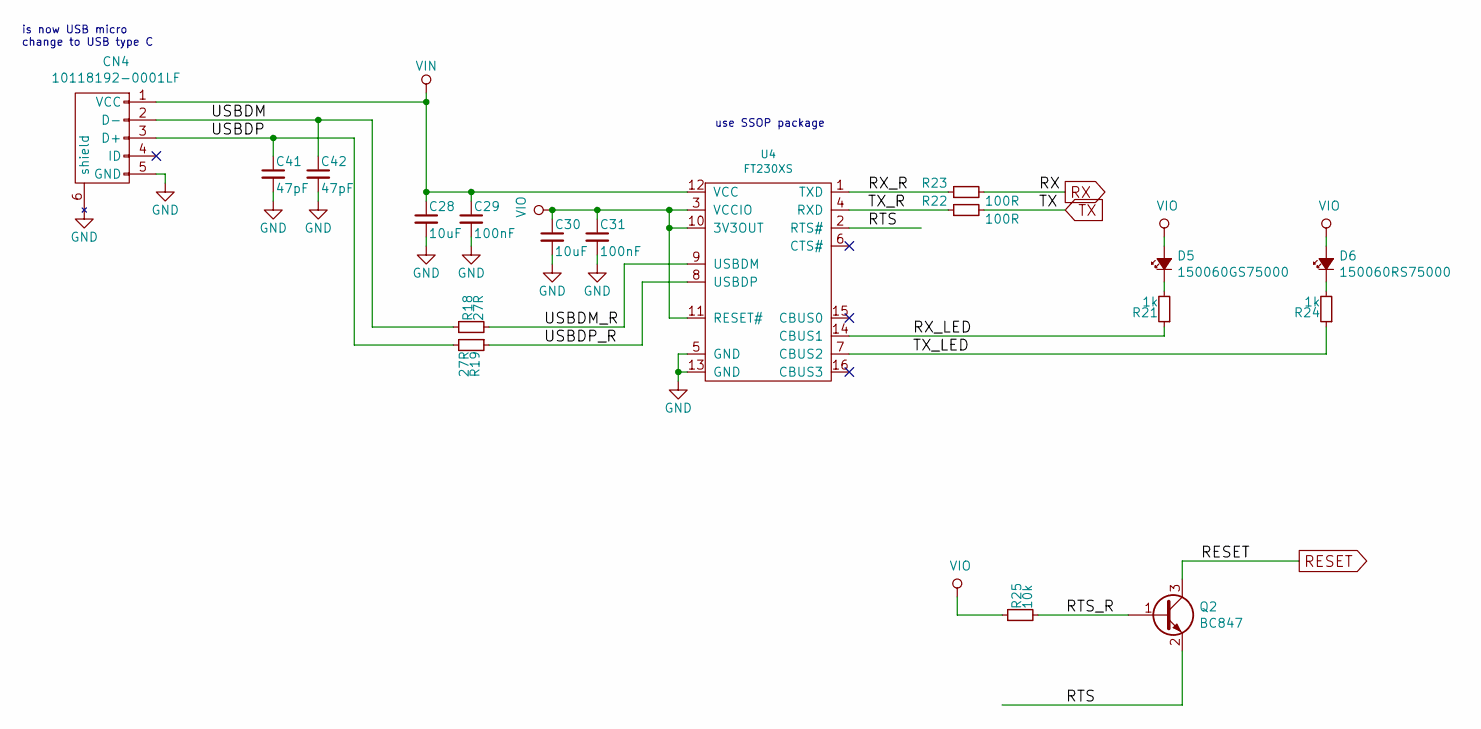
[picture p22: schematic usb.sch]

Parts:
C28, C30: 10uF; C_0603
C29, C31: 100nF; C_0603
C41, C42: 47pF; C_0603
CN4: 10118192-0001LF; 10118192-000xLF
D5: 150060GS75000; LED_0603
D6: 150060RS75000; LED_0603
Q2: BC847; SOT-23
R18, R19: 27R; R_0603
R21, R24: 1k; R_0603
R22, R23: 100R; R_0603
R25: 10k; R_0603
U4: FT230XS; SSOP-16_3.9x4.9mm_Pitch0.635mm

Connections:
/USB/RTS: Q2.2 (E), U4.2 (RTS#)
/USB/RTS_R: Q2.1 (B), R25.2
/USB/RX_LED: R21.1, U4.14 (CBUS1)
/USB/RX_R: R23.1, U4.1 (TXD)
/USB/TX_LED: R24.1, U4.7 (CBUS2)
/USB/TX_R: R22.1, U4.4 (RXD)
/USB/USBDM: C42.1, CN4.2 (D-), R18.1
/USB/USBDM_R: R18.2, U4.9 (USBDM)
/USB/USBDP: C41.1, CN4.3 (D+), R19.2
/USB/USBDP_R: R19.1, U4.8 (USBDP)
GND: C28.2, C29.2, C30.2, C31.2, C41.2, C42.2, CN4.5 (GND), CN4.6 (shield), U4.5 (GND), U4.13 (GND); also elsewhere on the board
unnamed: D5.1 (K), R21.2
unnamed: D6.1 (K), R24.2
RESET: Q2.3 (C); also elsewhere on the board
RX: R23.2; also elsewhere on the board
TX: R22.2; also elsewhere on the board
VIN: C28.1, C29.1, CN4.1 (VCC), U4.12 (VCC); also elsewhere on the board
VIO: C30.1, C31.1, D5.2 (A), D6.2 (A), R25.1, U4.3 (VCCIO), U4.10 (3V3OUT), U4.11 (RESET#)

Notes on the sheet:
is now USB micro change to USB type C
use SSOP package

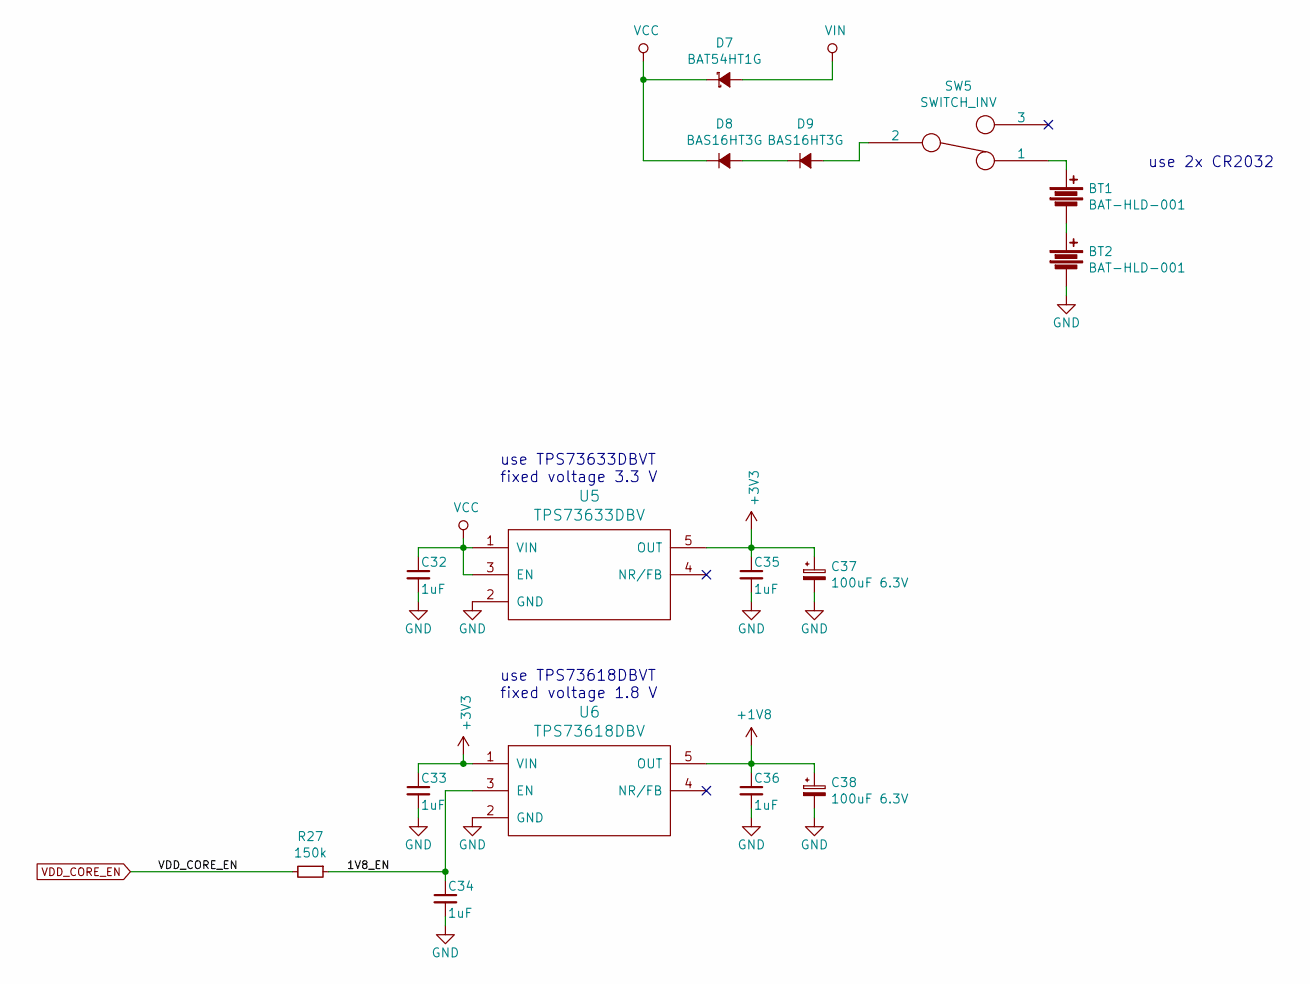
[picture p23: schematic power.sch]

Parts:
BT1, BT2: BAT-HLD-001; Wuerth_WA-BCMC_79523141
C32, C33, C34, C35, C36: 1uF; C_0603
C37, C38: 100uF 6.3V; TantalC_SizeD_EIA-7343_Reflow
D7: BAT54HT1G; SOD-323
D8, D9: BAS16HT3G; SOD-323
R27: 150k; R_0603
SW5: SWITCH_INV; WE_450404015514
U5: TPS73633DBV; SOT-23-5
U6: TPS73618DBV; SOT-23-5

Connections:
+1V8: C36.1, C38.1, U6.5 (OUT); also elsewhere on the board
+3V3: C33.1, C35.1, C37.1, U5.5 (OUT), U6.1 (VIN); also elsewhere on the board
/Power/1V8_EN: C34.1, R27.1, U6.3 (EN)
GND: BT2.2, C32.2, C33.2, C34.2, C35.2, C36.2, C37.2, C38.2, U5.2 (GND), U6.2 (GND); also elsewhere on the board
unnamed: BT1.1, SW5.1
unnamed: BT1.2, BT2.1
unnamed: D8.2 (A), D9.1 (K)
unnamed: D9.2 (A), SW5.2
VCC: C32.1, D7.1 (K), D8.1 (K), U5.1 (VIN), U5.3 (EN)
VDD_CORE_EN: R27.2; also elsewhere on the board
VIN: D7.2 (A); also elsewhere on the board

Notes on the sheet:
use TPS73633DBVT fixed voltage 3.3 V
use TPS73618DBVT fixed voltage 1.8 V
use 2x CR2032

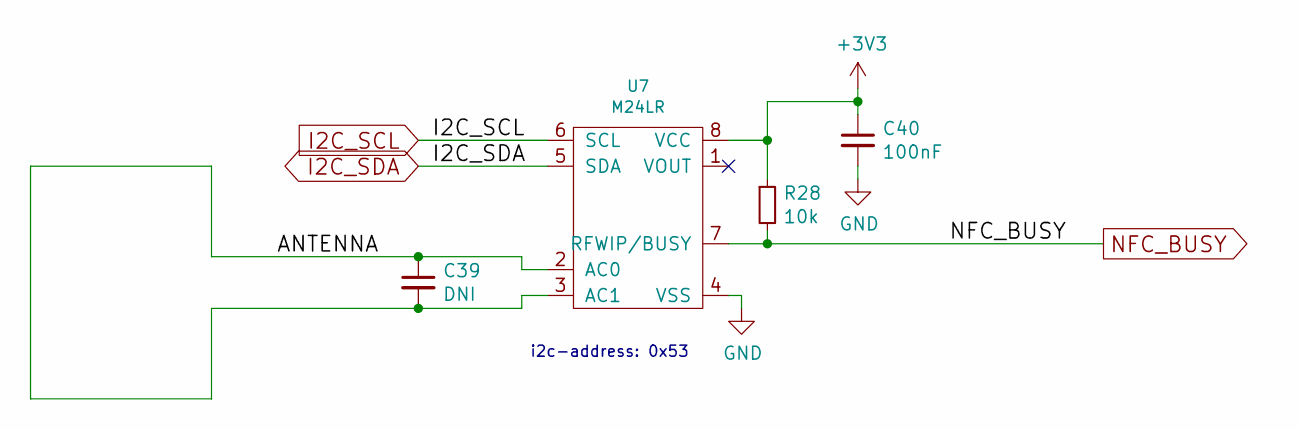
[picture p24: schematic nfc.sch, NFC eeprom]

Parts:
C39: DNI; C_0603
C40: 100nF; C_0603
R28: 10k; R_0603
U7: M24LR; SOIC-8_3.9x4.9mm_Pitch1.27mm

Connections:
+3V3: C40.1, R28.1, U7.8 (VCC); also elsewhere on the board
/NFC/ANTENNA: C39.1, C39.2, U7.2 (AC0), U7.3 (AC1)
GND: C40.2, U7.4 (VSS); also elsewhere on the board
I2C_SCL: U7.6 (SCL); also elsewhere on the board
I2C_SDA: U7.5 (SDA); also elsewhere on the board
NFC_BUSY: R28.2, U7.7 (RFWIP/BUSY); also elsewhere on the board

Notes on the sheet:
i2c-address: 0x53

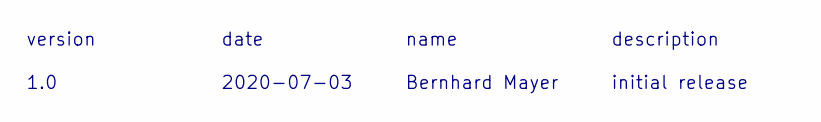
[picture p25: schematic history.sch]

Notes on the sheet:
version
date
name
description
1.0
2020-07-03
Bernhard Mayer
initial release

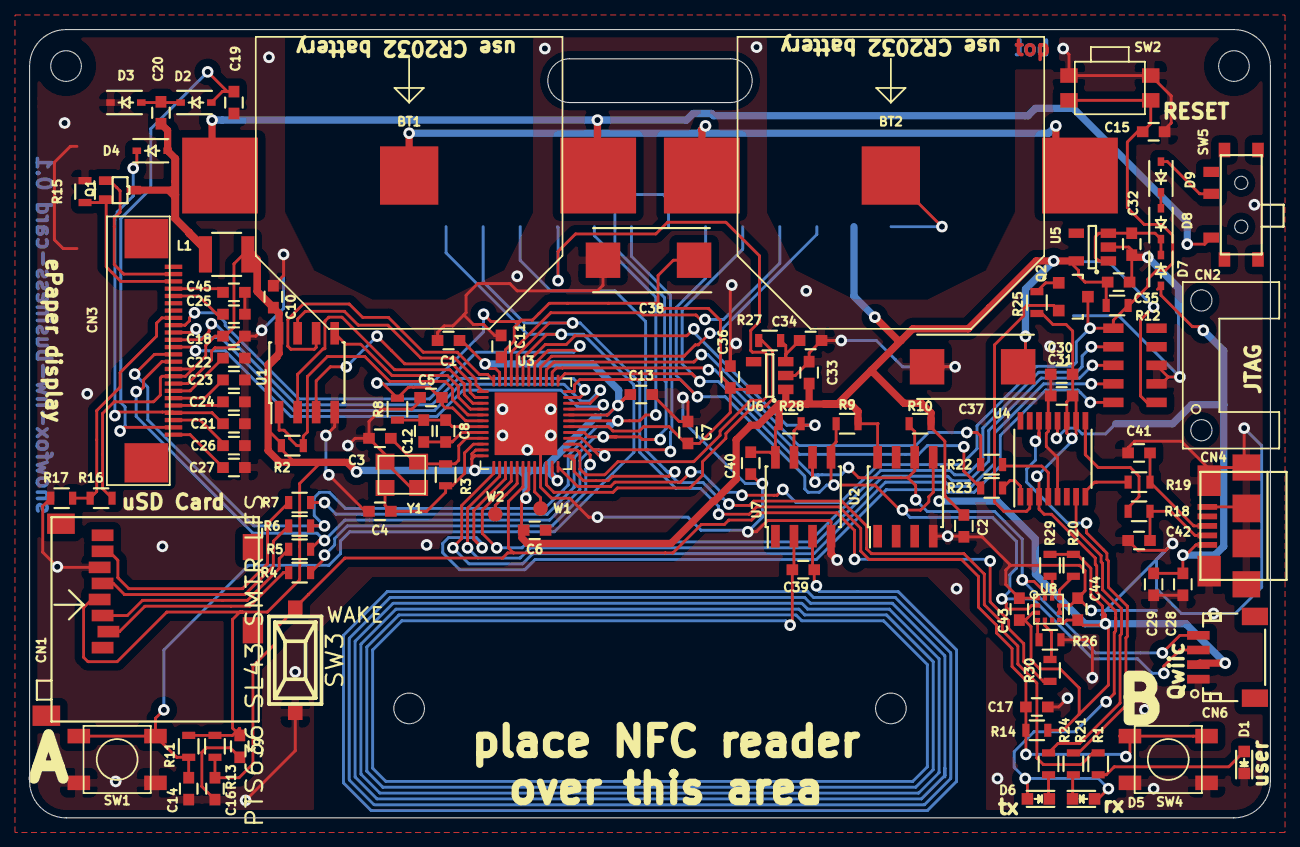
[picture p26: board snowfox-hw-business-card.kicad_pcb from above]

Board: 2 copper layers, 85.0 x 54.0 mm, 115 parts (1 on the bottom side), 85 nets.

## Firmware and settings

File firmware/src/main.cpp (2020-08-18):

/**
 * Snowfox is a modular RTOS with extensive IO support.
 * Copyright (C) 2017 - 2020 Alexander Entinger / LXRobotics GmbH
 *
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
 * You should have received a copy of the GNU General Public License
 * along with this program.  If not, see <http://www.gnu.org/licenses/>.
 */

/**************************************************************************************
 * This example program is tailored for usage with SiFive HiFive 1 Rev. B
 *
 * Electrical interface:
 *   LED = GPIO0
 *
 * Program via
 *   JLinkExe -device FE310 -if JTAG -speed 4000 -jtagconf -1,-1 -autoconnect 1
 *   > loadfile snowfox-vcard
 *   > exit
 **************************************************************************************/

/**************************************************************************************
 * INCLUDE
 **************************************************************************************/

#include <snowfox/hal/riscv64/FE310/Io.h>
#include <snowfox/hal/riscv64/FE310/Clock.h>
#include <snowfox/hal/riscv64/FE310/Delay.h>
#include <snowfox/hal/riscv64/FE310/DigitalOutPin.h>

/**************************************************************************************
 * NAMESPACES
 **************************************************************************************/

using namespace snowfox::hal;

/**************************************************************************************
 * CONSTANTS
 **************************************************************************************/

static uint32_t const HFXOSCIN_FREQ_Hz      =  16000000UL;
static uint32_t const CORECLK_FREQ_Hz       = 200000000UL;

static uint8_t  const LED_GPIO_NUMBER       = 0;

/**************************************************************************************
 * GLOBAL VARIABLES
 **************************************************************************************/

FE310::Delay         delay;
FE310::Clock         clock(&PRCI_HFXOSCCFG, &PRCI_PLLCFG, &PRCI_PLLOUTDIV, HFXOSCIN_FREQ_Hz);
FE310::DigitalOutPin led  (&GPIO0_INPUT_EN, &GPIO0_OUTPUT_EN, &GPIO0_IOF_EN, &GPIO0_OUTPUT_VAL, LED_GPIO_NUMBER);

/**************************************************************************************
 * MAIN
 **************************************************************************************/

int snowfox_main()
{
  clock.setClockFreq(static_cast<uint8_t>(FE310::ClockId::coreclk), CORECLK_FREQ_Hz);

  for(;;)
  {
    led.set();
    delay.delay_ms(250);
    led.clr();
    delay.delay_ms(250);
  }

  return 0;
}

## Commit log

2020-05-06 added files for project
    [snowfox-hw-business-card.kicad_pcb, snowfox-hw-business-card.sch]
2020-05-07 added some schematic pages from other projects
    [display.sch, history.sch, microcontroller.sch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]
2020-05-09 placed FE310, made first connections
    [microcontroller.sch]
2020-05-09 updated power circuit
    [microcontroller.sch, power.sch, usb.sch]
2020-05-10 added flash, JTAG connector and display to schematic
    [display.sch, microcontroller.sch, power.sch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]
2020-05-10 added nfc part, generated schematic pdf
    [display.sch, history.sch, microcontroller.sch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]
2020-05-11 started placement
    [display.sch, microcontroller.sch, power.sch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]
2020-05-12 made first placement
    [power.sch, snowfox-hw-business-card.kicad_pcb]
2020-05-12 added renderings of pcb
2020-05-12 added value 16 MHz to crystal, connected pin 1 of CN2 to +3V3
    [display.sch, history.sch, microcontroller.sch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]
2020-05-12 changed connector for display
    [display.sch, snowfox-hw-business-card.kicad_pcb]
2020-05-14 changed usb controller to FTDI FT230XS
    [snowfox-hw-business-card.kicad_pcb, usb.sch]
2020-05-14 added qwiic connector for I2C and grove connector for UART
    [microcontroller.sch, snowfox-hw-business-card.kicad_pcb]
2020-05-14 updated schematic pdf and renderings
    [display.sch]
2020-05-15 added BMA400 accelerometer
    [microcontroller.sch, snowfox-hw-business-card.kicad_pcb]
2020-05-19 changed JTAG connector
    [microcontroller.sch, snowfox-hw-business-card.kicad_pcb]
2020-06-02 used small side switch for reset, added expansion connector,changed mounting holes
    [microcontroller.sch, snowfox-hw-business-card.kicad_pcb, snowfox-hw-business-card.sch]
2020-06-02 updated pdf schematic
2020-06-02 changed to smaller crystal footprint
    [microcontroller.sch, snowfox-hw-business-card.kicad_pcb]
2020-06-02 routed some traces
    [snowfox-hw-business-card.kicad_pcb]
2020-06-07 changed diodes to smaller footprint, connected all lines in layout, updated images
    [display.sch, power.sch, snowfox-hw-business-card.kicad_pcb]
2020-06-07 made pcb edges round, added slot for mounting
    [snowfox-hw-business-card.kicad_pcb]
2020-06-07 rearranged parts for display
    [snowfox-hw-business-card.kicad_pcb, snowfox-hw-business-card.sch]
2020-06-07 reworked silk screen
    [snowfox-hw-business-card.kicad_pcb]
2020-06-10 changed wake button to smaller type, moved button A to left side, made some layout
    [microcontroller.sch, snowfox-hw-business-card.kicad_pcb]
2020-06-12 corrected some part numbers
    [display.sch, microcontroller.sch, power.sch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]
2020-06-14 added some missing part numbers
    [display.sch, microcontroller.sch, power.sch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]
2020-06-14 changed BMA400 to BMA253, changed SD-Card-Socket to MEM2061-01-188-00-A and changed battery holder to BAT-HLD-001 for cost reduction
    [microcontroller.sch, power.sch, snowfox-hw-business-card.kicad_pcb]
2020-06-15 optimized parts for BOM costs
    [display.sch, microcontroller.sch, power.sch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]
2020-06-15 connected interrupt line of BMA253, updated layout
    [microcontroller.sch, snowfox-hw-business-card.kicad_pcb, usb.sch]
2020-06-18 added test points, finished layout
    [microcontroller.sch, snowfox-hw-business-card.kicad_pcb]
2020-06-18 added pdf schematic
2020-07-02 exchanged rx and tx of usb serial
    [snowfox-hw-business-card.kicad_pcb, usb.sch]
2020-07-03 reworked reset circuit at usb serial
    [snowfox-hw-business-card.kicad_pcb, usb.sch]
2020-07-03 added C45 to pin4 of display
    [display.sch, history.sch, microcontroller.sch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]
2020-07-03 updated silk screen, added labels, added qrcode
    [snowfox-hw-business-card.kicad_pcb]
2020-07-03 updated images of pcb
2020-07-04 added snowfox logo
    [snowfox-hw-business-card.kicad_pcb]
2020-07-09 added pdfs of layout
    [snowfox-hw-business-card.kicad_pcb]
2020-07-09 added freecad files of complete business card, updated images
    [e-paper.step, snowfox-hw-business-card-complete.FCStd]
2020-07-09 added pin description to readme
2020-07-09 added i2c addresses to schematic pdf and readme
    [display.sch, history.sch, microcontroller.sch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]
2020-07-22 started display support frame
    [e-paper.step, snowfox-hw-business-card-complete.FCStd]
2020-07-23 updated display frame, updated renderings
    [snowfox-hw-business-card-complete.FCStd]
2020-07-26 added missing parts to 3d model, updated step file
    [microcontroller.sch, snowfox-hw-business-card-complete.FCStd, snowfox-hw-business-card.kicad_pcb]
2020-07-26 added production data for display frame
    [display_frame.step, display_frame.stl]
2020-08-15 Updated information on I2C of M24LR
2020-08-16 reworked display holder, increased some clearances, added hole for Qwiic connector
    [display_frame.step, display_frame.stl, snowfox-hw-business-card-complete.FCStd]
2020-08-18 Adding minimal firmware for blinking the LED of the FE310

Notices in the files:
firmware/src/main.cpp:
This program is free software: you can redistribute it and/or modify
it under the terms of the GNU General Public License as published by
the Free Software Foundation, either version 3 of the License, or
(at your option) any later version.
